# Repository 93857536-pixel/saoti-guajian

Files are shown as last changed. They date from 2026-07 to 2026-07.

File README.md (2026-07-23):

# 扫题挂件（Saoti GuaJian）

ESP32-S3 扫题挂件完整工程：固件、BLE Companion（iOS / watchOS / macOS）、USB 联调 App、装配与 3D 外壳。

## 仓库结构

| 目录 | 说明 |
|---|---|
| [`firmware/`](firmware/) | ESP32-S3 PlatformIO 固件（OV5640 / ST7789 / A7670G / BLE GATT / USB 串口） |
| [`companion/`](companion/) | **扫题挂件 App**（蓝牙）：iPhone + Apple Watch + Mac |
| [`macos-app/`](macos-app/) | macOS「SaotiCam」：USB 串口预览 / 联调 |
| [`hardware/`](hardware/) | 装配说明、接线、3D 外壳 STL/STEP |

架构：[`firmware/ARCHITECTURE.md`](firmware/ARCHITECTURE.md)  
BLE 协议：[`firmware/docs/BLE_COMPANION.md`](firmware/docs/BLE_COMPANION.md)

## 系统怎么用

1. 烧录 `firmware`（默认整机 env）
2. 屏上显示蓝牙名（如 `Saoti-F79D`）
3. 打开 **Companion App** →「设备」扫描连接（**不要**用 iPhone「设置 → 蓝牙」搜）
4. 短按 BOOT 或 App「扫题」→ 4G 调智谱 GLM-V → 答案经 BLE / 屏显示

AI 默认走 **4G only**（`NET_CELL_ONLY=1`）。USB 推流仍可用 Mac SaotiCam。

## Companion App（推荐日常使用）

```bash
cd companion
brew install xcodegen   # 若未安装
xcodegen generate
open SaotiCompanion.xcodeproj
```

| Scheme | 平台 |
|---|---|
| `SaotiCompanion` | iPhone（含 Watch App） |
| `SaotiCompanionMac` | Mac |

在 Xcode 填入 Team（Signing），真机调试蓝牙（模拟器无 BLE）。

功能：状态 / 远程扫题 / 答案全文 / 取景缩略图 / 补光；Watch 经 iPhone 转发命令。

## macOS USB 联调 App（SaotiCam）

```bash
cd macos-app
xcodegen generate
xcodebuild -scheme SaotiCam -configuration Debug -derivedDataPath build build
open build/Build/Products/Debug/SaotiCam.app
```

插入 CH343 / 原生 USB → 选端口 → 波特率 **115200**（4G）或 **921600**（USB 推流）→「连接」。

## 固件快速烧录

```bash
cd firmware
cp include/secrets.example.h include/secrets.h   # 首次，填入智谱 Key
pio run -e esp32s3-devkitc-1 -t upload          # 真屏 + 全功能（含 BLE）
# pio run -e esp32s3-devkitc-1-nolcd -t upload   # USB 推流联调（mock 屏）
# pio run -e esp32s3-devkitc-1-4gtest -t upload  # 4G 联调
```

常用串口命令：`?` 状态，`s` 扫题，`t` AI 测图，`DIAG` 4G，`V`/`v` USB 推流，`BLE` 自检广播。

关闭 BLE：编译加 `-DBLE_GATT_ENABLE=0`。

## 硬件要点

- 主控：YD-ESP32-S3 **N16R8**
- 摄像头：微雪 **OV5640 Camera Board (C)**（DVP；丝印 D2–D9→GPIO6–13）
- 屏幕：微雪 **1.3" ST7789**（`1/3/38/39/40/41`）
- 4G：FS-MCore **A7670**（ESP TX=21→模 RX，模 TX→ESP 2；PWK=47，PEN=48；VIN 独立 5V）
- 电池 ADC：GPIO14 分压
- 外壳 v7.36（76×110×58）：见 [`hardware/case/`](hardware/case/)，打印交付 `stl/saoti_front.stl` + `saoti_back.stl`

引脚以 [`firmware/include/pins.h`](firmware/include/pins.h) 为准。  
接线：[`hardware/WIRING.md`](hardware/WIRING.md)。

## License

个人/学习项目；按需自行补充许可证。

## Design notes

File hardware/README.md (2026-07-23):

# 硬件与外壳（v7.36）

| 文件 | 说明 |
|---|---|
| [`case/`](case/) | 卡扣外壳源码 + STL（**76×110×58 mm**） |
| [`case/PRINT.md`](case/PRINT.md) | 给商家打印说明 |
| [`case/COMPONENTS.md`](case/COMPONENTS.md) | 配件尺寸与舱位 |
| [`case/stl/saoti_front.stl`](case/stl/saoti_front.stl) / [`saoti_back.stl`](case/stl/saoti_back.stl) | **打印交付** |
| [`WIRING.md`](WIRING.md) / [`wiring_all.png`](wiring_all.png) | 全系统接线 |
| [`ASSEMBLY.md`](ASSEMBLY.md) | 装配长文（部分引脚可能过时，以 `firmware/include/pins.h` 为准） |
| [`给店家-接线说明.txt`](给店家-接线说明.txt) | 店家简版 |

生成外壳：

```bash
cd case
python3 generate_case.py
# 可选：配件就位预览
python3 generate_packed_assembly.py
```

材料：**PETG**；装配：卡扣，免胶免螺丝。

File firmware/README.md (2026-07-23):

# 扫题挂件固件

YD-ESP32-S3（N16R8）+ ST7789 + OV5640 + A7670。默认烧录即可用真屏整机固件。

3D 外壳（打印）：见 [`../hardware/case/PRINT.md`](../hardware/case/PRINT.md)，交付 `hardware/case/stl/saoti_front.stl` + `saoti_back.stl`。

**AI 解题**：默认 **只用 4G** 访问智谱 GLM-V（首选 `glm-4.6v`；用不了直接换 `glm-4v-flash`）。  
**4G**：开机拨号；SoftAP/家用 WiFi 已关闭（`NET_CELL_ONLY=1`）。预览可用 USB 串口推流。

## 功能清单

| 功能 | 状态 | 说明 |
|---|---|---|
| ST7789 显示 | 可用 | 状态页 + ASCII 答案摘要 |
| OV5640 拍照扫题 | 可用* | 短按 BOOT / 串口 `s` / SoftAP `/scan` |
| 无摄像头降级 | 可用 | 固定题图测 AI；长按 BOOT / `t` / SoftAP `/test` |
| SoftAP 控制台 | 默认关闭 | `NET_CELL_ONLY=1` 时不开热点 |
| 通义 VL 解题 | 4G + ESP-TLS | 模块只开 TCP，ESP32 mbedTLS 做 HTTPS |
| 4G A7670 | 默认 | 开机拨号；串口 `NET`/`DIAG`/`FW`/`HTEST` |
| USB 推流 | 可选 | 串口 `V`/`v` |

\* 成像质量取决于摄像头硬件与接线；微雪 C 型按 **D2–D9→GPIO6–13**（见 [WIRING.md](WIRING.md)）。

## 快速开始

```bash
cd firmware
cp include/secrets.example.h include/secrets.h   # 首次
# 编辑 secrets.h：OPENAI_API_KEY（智谱）+ 可上网 WiFi（CELL_ONLY 时可留空）
pio run -e esp32s3-devkitc-1 -t upload
```

1. 屏显示 Idle 提示（`BOOT to scan` 或 `BOOT=AI test`）
2. **短按 BOOT**：有摄像头则拍照解题；无摄像头则固定图测 AI  
3. **长按 BOOT ≈3s**：固定题图测 AI  
4. 手机连 SoftAP `SaotiCam` / `saoti1234` → `http://192.168.4.1/`  
5. 完整中文答案看 `/answer`

## 串口命令（115200）

| 命令 | 作用 |
|---|---|
| `s` | 扫题（同短按 BOOT） |
| `t` | 固定图 AI 测试 |
| `?` | JSON 状态 |
| `NET` / `DIAG` | 4G 诊断 |
| `V` / `v` | 开/关 USB 推流 |
| `APN=xxx` | 设置蜂窝 APN |
| `MODEL` | 查看当前视觉模型与已耗尽列表 |
| `MODEL=reset` | 清空「额度用尽」标记，从首选模型重试 |
| `SAY=文本` | TTS 播报（需接 UART 语音模块） |
| `TTS` / `TTSSTOP` | 查 TTS 状态 / 停止播报 |

## AI 配置

| 项 | 说明 |
|----|---|
| `include/secrets.h` | 智谱 Key + WiFi（已 gitignore） |
| 接口 | `open.bigmodel.cn/api/paas/v4/chat/completions` |
| 模型 | 默认 `glm-4.6v`；用不了直接换 `glm-4v-flash` |
| TTS | 可选 UART 模块 GPIO45/46；扫题成功自动播报 |

## 接线

详见 **[WIRING.md](WIRING.md)** 与 `include/pins.h`。

摘要：屏 SPI `1/3/38/39/40/41`；摄像 `4/5/6–13/15–18`；4G `ESP21→模RX`、`ESP2←模TX`、`PEN→48`、`PWK→47`；TTS `ESP45→模RX`、BUSY`46`；VIN 独立 5V。

## 环境

| env | 用途 |
|-----|---|
| `esp32s3-devkitc-1` | 整机（默认，启动探测 4G） |
| `esp32s3-devkitc-1-nolcd` | 无屏 USB 推流（跳过 modem） |
| `esp32s3-devkitc-1-4gtest` | 4G 联调 |
| `esp32s3-modem-bridge` | AT 透传 |
| `esp32s3-devkitc-1-mock` | 全 mock |

未配置 WiFi 时仍可 SoftAP 预览；解题需 STA 可上网。

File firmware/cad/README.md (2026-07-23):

# 3D 外壳（已迁走）

可打印外壳统一放在仓库根目录：

**[`../../hardware/case/`](../../hardware/case/)**

- 打印说明：[`PRINT.md`](../../hardware/case/PRINT.md)
- 配件尺寸：[`COMPONENTS.md`](../../hardware/case/COMPONENTS.md)
- 交付 STL：`saoti_front.stl` / `saoti_back.stl`（在 `stl/`）
- 生成：`python3 generate_case.py`

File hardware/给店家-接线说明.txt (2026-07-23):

================================================================================
  扫题挂件 — 给手机店 / 维修店师傅的完整接线说明
  （客户全部配件一次性安装，请严格按此操作，接完拍照发客户）
================================================================================

【客户配件清单 — 共 11 件，本说明全部覆盖】

  序号  配件名称                          本说明章节
  ────  ────────────────────────────────  ──────────
  1     YD-ESP32-S3 开发板                二、七
  2     OV5640 自动对焦摄像头             五
  3     ST7789 1.3寸 240×240 裸屏 12Pin   四
  4     FS-MC615-A7670CX 4G 模块 + 天线   三
  5     TP4056 Type-C 充放保护板          二-A
  6     603450 锂电池（带保护）           二-A
  7     MT3608 升压模块                   二-A、二-B
  8     2位独立按键模块（双键板）         六
  9     杜邦线 / 飞线                     全文
  10    Type-C 充电线（给 TP4056 充电）   二-A
  11    1000µF 16V 电解电容               二、三

  客户自备（本次可不装）：Nano SIM 物联卡、3D 打印外壳、万用表

【固件引脚已固定，必须按本说明接，否则 4G / 屏 / 摄像头无法工作】

================================================================================
★★★ 最重要：禁止把 4G 板直接叠插在 ESP32 排针上 ★★★
================================================================================

  · 必须用杜邦线/飞线逐根连接，不能整板对插！
  · 对插容易错一格，会出现 GND 接到 VIN，烧模块！
  · 4G 的 VIN 必须接 5V（右侧 5V 脚），不能靠叠插取电
  · 4G 的 TX/RX 必须交叉接到「模 RX←ESP 21」「模 TX→ESP 2」，不能接到左侧 TX/RX 字样（那是 USB）
  · 勿接旧表「TX→47 / PWK→41」（47 是 PWK，41 是屏幕背光）

================================================================================
一、安全（必看）
================================================================================

1. 电池红线 = 正，黑线 = 负，接反会烧板。
2. 先调 MT3608 空载到 5.0V，再接 ESP32 和 4G。
3. 4G 模块 VIN 必须 5V，禁止接 3.3V。
4. 1000µF 电容：长脚 + 接 5V，短脚 − 接 GND，不能接反。
5. 全部模块 GND 必须连在一起（共地）。
6. 4G 天线插紧；测试时不要用手握天线。
7. 接好线后若发烫、冒烟、有糊味，立即断电。

================================================================================
二、电源系统（TP4056 + 电池 + MT3608 + 电容）
================================================================================

── 二-A：TP4056 与电池 ──────────────────────────────────────

  TP4056 丝印        接什么
  ─────────────────────────────────────────────────────────
  B+  / BAT+         电池红线（+）
  B-  / BAT-         电池黑线（−）
  OUT+               红色导线 → MT3608 IN+
  OUT-               黑色导线 → MT3608 IN-（GND 母线）
  USB Type-C         Type-C 充电线（仅充电，不接 ESP32）

  ★ 建议：先不接电池，用 USB 给 TP4056 充电测试；最后一步再装电池。

── 二-B：MT3608 升压（必须调到 5.0V）────────────────────────

  MT3608 丝印        接什么
  ─────────────────────────────────────────────────────────
  IN+                TP4056 OUT+
  IN-                TP4056 OUT-
  OUT+               5V 红色母线（用万用表测量后再接负载）
  OUT-               GND 黑色母线

  调压步骤：
    1. 只接 TP4056 → MT3608，不接 ESP32 和 4G
    2. 给 TP4056 接 USB 或电池，输入约 3.7～4.2V
    3. 万用表测 MT3608 的 OUT+ 与 OUT- 之间电压
    4. 用小螺丝刀慢慢拧 MT3608 上的电位器，调到 5.0V（4.9～5.1 均可）
    5. 电压稳定后再往下接

── 二-C：5V 母线分配 ─────────────────────────────────────────

  MT3608 OUT+ (5V) ──┬── ESP32 右侧 5V
                     ├── 4G 模块 VIN
                     └── 1000µF 电容 +（靠近 4G 模块）

  MT3608 OUT- (GND) ─┬── ESP32 GND
                     ├── 4G 模块 GND
                     ├── TP4056 OUT-
                     ├── 屏幕 GND
                     ├── 摄像头 GND
                     └── 1000µF 电容 −

  屏幕、摄像头 3.3V ── ESP32 右侧 3V3（各一根，可并联）

  ★ ESP32 调试时可用 USB 线供电；装电池后整机由 MT3608 供电。
    不要 USB 和 MT3608 5V 同时硬并在一起（二选一或只接一种主供电）。

================================================================================
三、4G 模块 FS-MC615-A7670CX（对照模块边缘丝印）
================================================================================

  模块丝印     接到 ESP32 板子丝印         说明
  ─────────────────────────────────────────────────────────
  VIN          独立 5V≥2A（勿只靠 USB）    必须 5V，电流要够
  GND          GND                         共地
  RX           21（左侧排针「21」）        模块收 ← ESP 发（交叉！）
  TX           2（右侧排针「2」）          模块发 → ESP 收（交叉！）
  PWK          47（左侧排针「47」）        开机控制（固件脉冲）
  PEN          48 或 3V3                   使能，必须常高/常接 3.3V
  NET          悬空                        勿接 GPIO2（会顶 UART RX）
  天线座       FPC 天线                    插紧，金属面朝外

  ★ 左侧「TX」「RX」字样两针 = USB 口，不要接 4G！
  ★ 41=屏幕背光，勿再接 PWK；旧表「TX→47 / PWK→41 / NET→2」已作废。
  ★ 没插 SIM 卡也可以先接线测 AT（客户自己插卡）。

================================================================================
四、ST7789 1.3 寸裸屏 12Pin（3.3V，SPI）
================================================================================

  屏幕引脚名（常见）     接到 ESP32 丝印
  ─────────────────────────────────────────────────────────
  GND                    GND
  VCC / 3.3V             3V3
  SCL / SCLK             3
  SDA / MOSI / DIN       1
  CS                     38
  DC / RS                39
  RES / RST              40
  BL / 背光              41（或先接 3.3V 常亮试背光）

  ★ 以固件 pins.h 为准：MOSI=1 SCLK=3 CS=38 DC=39 RST=40 BL=41
  ★ 裸屏 12Pin 各卖家线序可能不同，必须对照客户提供的商家图纸！
  ★ 用万用表确认 VCC 脚后再上电，防止 VCC 接到信号脚烧屏。
  ★ 建议焊接或热缩管固定，杜邦线容易松。

================================================================================
五、OV5640 自动对焦摄像头（3.3V + 排线/多信号线）
================================================================================

  摄像头信号              接到 ESP32 丝印
  ─────────────────────────────────────────────────────────
  3.3V / VCC              3V3
  GND                     GND
  SDA / SIOD              4
  SCL / SIOC              5
  D0                      6
  D1                      7
  D2                      8
  D3                      9
  D4                      10
  D5                      11
  D6                      12
  D7                      13
  VSYNC                   16
  HREF                    17
  PCLK                    18
  XCLK                    15
  PWDN / RESET            可不接（悬空）

  排线安装：
    · 断电操作
    · 金属触点朝向 PCB
    · 插到底，扣紧卡扣
    · 撕掉镜头保护膜

  ★ 若摄像头是带转接板的小 PCB，请对照转接板丝印与上表连接。

================================================================================
六、拍照按键（2 位独立按键模块，双大方键板）
================================================================================

  客户配件：天猫「2位独立按键模块」（整板，不是单颗 6×6）。
  常见排针丝印：GND / KEY1 / KEY2（有的还有 VCC，接 3V3）。

  接线（装 3D 壳推荐）：
    KEY1 ──► ESP32 丝印「0」或 BOOT     （扫题）
    KEY2 ──► ESP32 丝印「42」           （测 AI）
    GND  ──► GND
    VCC  ──► 3V3（若模块有此脚）

  裸板联调也可先只按板载 BOOT（=GPIO0，等同 KEY1）。
  3D 外壳：后壳左侧壁双键方窗，模块从内侧嵌入。

================================================================================
七、USB 调试线（客户电脑烧录/测试用）
================================================================================

  · Type-C / Micro USB 线接 ESP32 上标「USB」或「COM」的口 → 电脑
  · 左侧 TX/RX 已被 USB 芯片占用，不要再接其他线

================================================================================
八、推荐安装顺序（师傅按步骤来）
================================================================================

  步骤 1   TP4056 + MT3608 接线，先不装电池
  步骤 2   万用表把 MT3608 调到 5.0V
  步骤 3   5V/GND 接 ESP32，上电看板载蓝灯亮、不发热
  步骤 4   接 ST7789 屏幕（3.3V + 35～40），看背光
  步骤 5   断电，插 OV5640 排线/信号线，再上电
  步骤 6   接 4G：VIN/GND/PEN/PWK/RX/TX/天线 + 1000µF 电容
  步骤 7   装 603450 电池到 TP4056（最后一步）
  步骤 8   全机共地检查、理线、固定（双面胶/热熔胶）
  步骤 9   拍照发客户（见下方清单）

================================================================================
九、接完必拍照片（发客户微信）
================================================================================

  [ ] 1. 整机俯视（所有模块可见）
  [ ] 2. 4G 模块接线特写（能看清 VIN/GND/RX/TX/PEN/PWK）
  [ ] 3. 电源接线特写（TP4056、MT3608、电容、电池）
  [ ] 4. 屏幕 / 摄像头接线特写
  [ ] 5. 万用表测 4G VIN 对 GND = 约 5.0V 的照片

================================================================================
十、接完自检清单（师傅打勾）
================================================================================

  电源
  [ ] MT3608 输出 5.0V（4.8～5.2V）
  [ ] 4G VIN 对 GND ≈ 5V（不是 0V，不是 3.3V）
  [ ] 4G PEN 对 GND ≈ 3.3V
  [ ] 1000µF 电容已装，正负未接反
  [ ] 所有 GND 相通

  4G
  [ ] 4G RX 接 ESP32「21」（不是左侧 TX/RX 字样）
  [ ] 4G TX 接 ESP32「2」（模块 TX → ESP 2，交叉）
  [ ] 4G PWK 接 ESP32「47」
  [ ] 4G PEN 接 ESP32「48」或 3V3
  [ ] 天线已插
  [ ] 没有用叠插方式连接（必须杜邦线/飞线）

  屏幕 / 摄像头
  [ ] 屏幕 VCC 接 3.3V（不是 5V）
  [ ] 屏幕 SPI：MOSI=1 SCLK=3 CS=38 DC=39 RST=40 BL=41
  [ ] 摄像头排线卡扣锁紧
  [ ] 摄像头 3.3V / GND 正确

  按键
  [ ] KEY1→GPIO0 扫题；KEY2→GPIO42 休眠/唤醒（或 BOOT 并联 KEY1）

  安全
  [ ] 无发烫、冒烟、糊味
  [ ] 电池正负未接反

================================================================================
十一、快速对照表（扫一眼）
================================================================================

  ESP32 丝印    接什么
  ─────────────────────────────────────
  5V            MT3608 OUT+、4G VIN、电容+
  3V3           4G PEN、屏幕 VCC、摄像头 VCC
  GND           全部 GND 汇在一起、电容−
  21            4G RX（模块的 RX 脚）← ESP 发
  2             4G TX（模块的 TX 脚）→ ESP 收
  47            4G PWK
  48            4G PEN（或直连 3V3）
  1             屏幕 MOSI/SDA
  3             屏幕 SCLK/SCL
  38            屏幕 CS
  39            屏幕 DC
  40            屏幕 RST
  41            屏幕 BL 背光
  4～18         摄像头（见第五节）
  0             KEY1 扫题 / BOOT
  42            KEY2 休眠/唤醒
  45            TTS TX（可选语音模块）
  46            TTS BUSY（可选）
  TX / RX       仅 USB，不接 4G

================================================================================
十二、常见错误（务必避免）
================================================================================

  ✗ 4G 板叠插在 ESP32 排针上           → 必烧或必乱
  ✗ GND 接到 4G VIN                    → 模块无电
  ✗ 4G TX/RX 接到左侧 TX/RX 字样       → 与 USB 冲突
  ✗ 4G VIN 接 3.3V                     → 模块不工作
  ✗ PEN 未接 3.3V                      → 模块不开机
  ✗ 屏幕 VCC 接 5V                     → 烧屏幕
  ✗ MT3608 超过 5.5V                   → 烧 ESP32/4G
  ✗ 电容正负接反                       → 危险

================================================================================
  接完后客户会用电脑烧录/测试；SIM 卡与 APN 由客户配置（固件 include/config.h 中 CELL_APN）。
  文档版本：2026-07-23  与生产固件 pins.h 一致（4G: TX/RX=21/2 PWK=47 PEN=48；屏: 1/3/38-41；摄: 4-18；键: 0/42）
================================================================================

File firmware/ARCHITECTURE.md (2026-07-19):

# 扫题挂件 — 项目总体架构

## 1. 系统目标

ESP32-S3「扫题挂件」：BOOT 键/串口触发 OV5640 拍照 → WiFi SoftAP 或 4G 上传 → ST7789 显示状态；Mac **SaotiCam** 可通过 USB 或 WiFi MJPEG 预览。

## 2. 最终接线（YD-ESP32-S3 N16R8）

| 模块 | 信号 | ESP 丝印 | 备注 |
|---|---|---|---|
| 微雪 ST7789 | VCC/GND | 3V3 / G | 勿用 5V 强行直灌裸屏 |
| | DIN/CLK/CS/DC/RST/BL | **1 / 3 / 38 / 39 / 40 / 41** | 勿用 35–37（OPI PSRAM） |
| OV5640 | SCCB/DVP | 4–5, 6–13, 15–18 | 既有映射 |
| FS-MCore 4G | TX/RX/PEN/PWK | 模TX→**2**，模RX→**21**，PEN→**48**，PWK→**47** | VIN 独立 5V≥2A；NET 悬空 |
| 拍照键 | 板载 BOOT | **0** | 短按拍照；3D 壳开孔露出，不另接按键 |

```
电源: 电池 → TP4056 → MT3608(5.0V) → ESP 5V + 4G VIN（共地，近 4G 加 1000µF）
```

## 3. 固件模块

```
main.cpp
  ├─ Display     ST7789（TFT_eSPI + HSPI）
  ├─ Camera      OV5640 JPEG
  ├─ Modem       A7670 AT + SoftAP WiFi 双路径
  ├─ Button      GPIO0
  ├─ UsbStream   SC 协议推流
  ├─ StreamServer SoftAP MJPEG :80
  └─ ble_gatt    BLE Companion GATT（Saoti-XXXX）
```

流程：`Idle → 按键/s → Capture → Upload → Result → Idle`

## 4. 编译环境

| env | 用途 |
|-----|---|
| `esp32s3-devkitc-1` | **默认整机**：真屏+摄+4G 快探+USB/WiFi 推流 |
| `esp32s3-devkitc-1-nolcd` | 无屏 USB 推流联调 |
| `esp32s3-devkitc-1-4gtest` | 专注 4G AT |
| `esp32s3-modem-bridge` | 电脑直发 AT 透传 |
| `esp32s3-devkitc-1-mock` | 全 mock |

```bash
cd firmware
pio run -e esp32s3-devkitc-1 -t upload
```

## 5. 使用

1. 上电后屏显示 Boot → Ready / net offline  
2. 手机连 SoftAP `SaotiCam` / `saoti1234`，打开 `http://192.168.4.1/`  
3. 按 **BOOT** 或串口发 `s` 拍照上传  
4. Mac：原生 USB 或 CH343；`V` 开 USB 推流，`m` 做 4G 深诊断  

## 6. 已知限制

| 项 | 说明 |
|----|---|
| 4G 仅红灯 | 模块未开机，需独立 5V≥2A；程序已快失败，不阻塞整机 |
| GPIO35–37 | N16R8 OPI 占用，不能接屏 |
| GPIO47 | PSRAM 时钟干扰，不能接 4G RX |

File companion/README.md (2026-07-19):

# 扫题挂件 Companion（iOS / watchOS / macOS）

通过 **蓝牙** 连接 ESP32 扫题挂件：状态、远程扫题、答案全文、取景缩略图、补光。

固件协议见 [`../firmware/docs/BLE_COMPANION.md`](../firmware/docs/BLE_COMPANION.md)。

## 打开工程

```bash
cd companion
xcodegen generate
open SaotiCompanion.xcodeproj
```

| Scheme | 平台 |
|---|---|
| `SaotiCompanion` | iPhone（含 Watch App） |
| `SaotiCompanionMac` | Mac |

在 Xcode 里填入你的 **Team**（Signing），真机调试蓝牙（模拟器无 BLE）。

## 功能

- **控制**：电量 / 4G / 相位；一键扫题、唤醒、补光  
- **取景**：按需拉一帧缩略图（非实时流）  
- **答案**：当前全文 + 本地历史  
- **设备**：扫描 `Saoti-*`、连接、日志  
- **Watch**：扫题 / 唤醒 / 进度与答案摘要（依赖 iPhone 已连挂件）

## 重要

iPhone「设置 → 蓝牙」**不会**列出本挂件（自定义 GATT）。请在本 App「设备」页扫描；对照挂件屏幕上的 `Saoti-XXXX`。

## 权限

- `NSBluetoothAlwaysUsageDescription`  
- Background：`bluetooth-central`（扫题过程中保持连接）

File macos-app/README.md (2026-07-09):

# SaotiCam macOS 客户端

在 Mac 上通过 WiFi 实时查看 ESP32-S3 + OV5640 摄像头的 MJPEG 视频流。

## 前置条件

1. 已将 [saoti-guajian-fw](../saoti-guajian-fw/) 固件烧录到 ESP32-S3 开发板
2. 摄像头模块接线正确，串口可看到 `[STREAM] MJPEG http://...` 日志
3. macOS 已安装 Xcode 与 xcodegen（`brew install xcodegen`）

## 快速开始

### 1. 烧录固件

```bash
cd ../saoti-guajian-fw
python3 -m platformio run -e esp32s3-devkitc-1-nolcd -t upload
```

若 `config.h` 中 `WIFI_SSID` 仍为 `"YOUR_SSID"`，设备会自动开启 SoftAP，无需家庭 WiFi。

### 2. 连接网络

**方式 A — Mac 直连热点（默认）**

| 项目 | 值 |
|---|-----|
| WiFi 名称 | `SaotiCam` |
| 密码 | `saoti1234` |
| 设备 IP | `192.168.4.1` |

在 Mac 系统设置 → WiFi 中连接 `SaotiCam` 热点。

**方式 B — 同一局域网**

在固件 `config.h` 填写家庭 WiFi 的 `WIFI_SSID` / `WIFI_PASS`，烧录后查看串口日志中的 STA IP（如 `192.168.1.xxx`），Mac 连同一 WiFi 后在 App 输入该 IP。

### 3. 编译运行 macOS App

```bash
cd /Users/linminhao/Documents/saoti-guajian-ios
xcodegen generate
open SaotiCam.xcodeproj
```

在 Xcode 中选择 **My Mac** 运行，或命令行构建：

```bash
xcodebuild -scheme SaotiCam -destination 'platform=macOS' build
```

构建完成后可在 `DerivedData` 或 Xcode 中直接 Run 启动 App。

### 4. 使用 App

**USB 串口（推荐，无需 WiFi）**

1. ESP32 用 USB 线连 Mac（烧录口即可）
2. 打开 SaotiCam，连接方式选 **USB 串口**
3. 串口选 `cu.usbserial-...`，点击 **连接**

**WiFi**

1. Mac 连接 `SaotiCam` 热点或同一局域网
2. 连接方式选 **WiFi**，IP 填 `192.168.4.1`（或 STA IP）
3. 点击 **连接**

点击画面可隐藏/显示控制栏；点击 **断开** 停止拉流。

> USB 模式固件默认跳过 4G 初始化，启动更快、串口不被 AT 日志干扰。

## HTTP 端点（固件提供）

| 路径 | 说明 |
|---|---|
| `GET /stream` | MJPEG 实时流（multipart/x-mixed-replace） |
| `GET /capture` | 单张 JPEG 快照 |
| `GET /` | 状态页（含流预览链接） |

## 故障排查

- **连接失败**：确认 Mac 已连上 `SaotiCam` 热点或同一局域网；浏览器访问 `http://192.168.4.1/` 验证
- **无画面**：查看串口是否有 `[CAM]` / `[STREAM]` 日志；确认 OV5640 初始化成功
- **ATS 报错**：App 已配置本地 HTTP 例外；若 IP 不在 192.168.x.x 段，需在 `Info.plist` 补充对应域

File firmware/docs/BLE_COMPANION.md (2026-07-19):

# 扫题挂件 BLE Companion 协议

ESP32-S3 **硬件自带 BLE**；固件启用 GATT 后，广播名形如 `Saoti-XXXX`（MAC 后四位）。

Apple 工程：[`../../companion`](../../companion)（iOS / macOS / watchOS）。

## 服务 UUID

| 角色 | UUID |
|---|---|
| Service | `6E400001-B5A3-F393-E0A9-E50E24DCCA9E` |
| STATUS（Read+Notify） | `6E400002-…` |
| COMMAND（Write） | `6E400003-…` |
| ANSWER（Read+Notify） | `6E400004-…` |
| THUMB（Notify） | `6E400005-…` |
| EVENT（Notify） | `6E400006-…` |

协议版本：`fw_proto=1`（见 STATUS JSON）。

## COMMAND 文本

| 命令 | 作用 |
|---|---|
| `ping` | EVENT 回 `pong` |
| `scan` / `s` | 触发扫题（等同 BOOT） |
| `wake` | 唤醒摄像头/4G |
| `thumb` / `preview` | 抓一帧 QVGA 预览图经 THUMB 下发（非扫题原图） |
| `flash=1` / `flash=0` | 补光开关 |
| `status` | 立即推送 STATUS |
| `answer` | 推送当前答案 |

## STATUS JSON（节选）

`cam` `lcd` `cell` `bat_pct` `charging` `csq` `sleeping` `busy` `phase` `fw` `fw_proto` `ble` `has_answer` `last_error` …

`phase`：`idle` | `capturing` | `uploading` | `result`

## THUMB 分片

1. 首包 8 字节：`THMB` + `uint32` little-endian 长度  
2. 后续 Notify：JPEG 原始字节（约 180B/包）

## 烧录与验证

```bash
cd firmware
pio run -e esp32s3-devkitc-1 -t upload
# 串口应出现：[BLE] advertising as Saoti-XXXX
```

手机/Mac 打开 **扫题挂件** App → 设备页扫描 → 连接 → 控制页扫题。

## 重要：为什么「手机设置 → 蓝牙」搜不到？

| 平台 | 系统蓝牙设置 |
|---|---|
| **iPhone / iPad** | **永远不会**列出本挂件（自定义 GATT，非耳机/键盘类） |
| **Android** | 部分机型在「配对新设备」里能看到 `Saoti-XXXX`，但仍需 App 才能扫题 |
| **正确做法** | 打开 **扫题挂件 Companion App** →「设备」→ 扫描 → 点 `Saoti-XXXX` |

挂件屏幕空闲时会显示蓝牙名（如 `Saoti-F79D`）和「请用扫题挂件App连接」。

## 说明

- V1 **不做** BLE 实时视频；实时预览仍用 SoftAP/USB（Mac SaotiCam）。  
- Watch 经 iPhone WatchConnectivity 转发，不直接连挂件。  
- 关闭 BLE：编译加 `-DBLE_GATT_ENABLE=0`。

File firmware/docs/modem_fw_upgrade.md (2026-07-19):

# FS-MCore A7670G 基带固件升级（解决 HTTPS 715）

本机实测（2026-07-18 `FW`）：

| 项 | 值 |
|----|-----|
| Model | **A7670G-LABE** |
| Revision | **A110B06A7670M7**（`A7670M7_B06V01_241111`） |
| ATI 显示 | V1.11.2 |
| IMEI | `867284069506675` |
| 现象 | `httpbin.org` HTTPS OK；百炼 → **715 SSL 失败** |

**结论：本机已是公开渠道最新的 LABE 包（A110B06），再刷同一包通常无效。**  
若店家另有更新私有包可再试；否则应改走 **ESP 侧 TLS（方案 1）**，不要刷 LASE/LLSE。

---

## 警告（必读）

1. **只能刷 A7670G-LABE 包**。刷成 LASE / LLSE / A7670E 等会导致变砖或反复重启。
2. 升级工具是 **Windows** 程序；Mac 不能直接烧录基带。
3. 用 **V1.32** 烧录工具，**不要**用有 bug 的 V1.13。
4. 升级前记下 `FW` 输出的完整 `AT+SIMCOMATI` 和 IMEI；个别包会清 IMEI，可用 `AT+SIMEI="你的号码"` 写回。
5. **优先问店家**要「A7670G-LABE」官方升级包；第三方包仅作备选。

---

## 需要准备

- Windows 电脑
- 模块 **Type-C USB** 线
- 模块 **VIN 独立 5V ≥2A**（升级时也建议外供），GND 与电脑共地
- PEN 接 3.3V（或 ESP 的 3V3）
- 驱动 + 烧录工具（LilyGo 汇总，与 SIMCom MADL 同源）：
  - 驱动：[Windows USB Drivers](https://drive.google.com/drive/folders/1-7x2z00a5VO7GZS96C6mDupNTBXIh--H)
  - 工具（选 **V1.32**）：[A7670X/A7608X Flash Tools](https://drive.google.com/file/d/12nt5-wcsUT6bRaEhfOMBSq0EhOl8R2by/view?usp=sharing)
- 固件包（**仅 LABE**，备选）：
  - 🆕 [A7670G-LABE A110B06](https://drive.google.com/file/d/10fsorFI8SuTlcffufgphpYbt2JjUpqtg/view?usp=sharing)
  - 回退用 [A7670G-LABE A069B01](https://drive.google.com/file/d/10oSTTqhw7ZiiZ_LiqAb3WYV3LXwbpKtV/view?usp=sharing)

图文总览（LilyGo）：  
https://github.com/Xinyuan-LilyGO/LilyGo-Modem-Series/blob/main/docs/cn/update_fw.md  
视频参考：https://youtu.be/AZkm-Z7mKn8

---

## 步骤

### 1. 升级前备份版本

ESP 已接好时，串口（115200）发：

```text
FW
```

应看到 `Model: A7670G-LABE`。把整段 `SIMCOMATI` 复制保存。

或用店家 **FreeAT**：模块 USB 插 Windows → `AT+SIMCOMATI`。

### 2. 进入升级模式（BOOT）

FS-MCore 上找 **BOOT / SBOOT / BOOT_N** 焊盘或按键（店家资料图为准）：

1. **按住 BOOT 不放**
2. 插上模块 Type-C（必要时再接 VIN 5V）
3. Windows「设备管理器」出现下载口 / 未知设备后，再松开 BOOT
4. 按工具说明给所有未知设备装驱动（可能有多个，逐个装完）

若没有按键：用杜邦线在上电瞬间把 BOOT 脚拉到说明书要求的电平（通常对地或对 1.8V，以店家为准）。

### 3. 用 MADL V1.32 烧录

1. 解压固件包，打开 **`A76XX_A79XX_MADL V1.32 Only for Update`**
2. 选择解压出的 **A7670G-LABE** 镜像目录
3. 选中设备管理器里的下载 COM 口
4. 点 **GO**，等进度条跑完，不要中途拔线

### 4. 升级后核对

正常上电（不必再按 BOOT），串口发：

```text
FW
```

期望类似：

```text
Model: A7670G-LABE
Revision: A110B06A7670M7
...
```

然后：

```text
HTEST
t
```

- `HTEST` → httpbin 仍应 200  
- `t` → 若百炼不再 715，说明 TLS 已改善  

若 IMEI 变空：在 FreeAT / 透传里执行 `AT+SIMEI="原IMEI"`（以 SIMCom 手册为准）。

---

## 失败时

| 情况 | 处理 |
|---|---|
| 刷错成 LLSE/LASE | 立刻用 **LABE** 包再刷回去 |
| A110B06 后不稳定 | 回退 **A069B01**，再考虑方案 1（ESP 侧 TLS） |
| 仍 715 | 升级未必能覆盖百炼的密码套件；改走 ESP mbedTLS over 4G TCP |

升级完成后把串口 `FW` + `HTEST` / `t` 日志发我，我帮你看是否打通百炼。

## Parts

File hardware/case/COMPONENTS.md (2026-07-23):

# 配件尺寸 + 舱位安装（外壳 v7.36）

> 外廓 **76×110×58**。挂绳耳对接；卡扣台肩；止口连体；四角/勾尖留壁 ≥0.5 mm。

## 1. 配件尺寸

| 配件 | 平面 (mm) | 备注 |
|---|---|---|
| YD-ESP32-S3 | 64 × 28.4 | 烧录口 **12×5** |
| 微雪 1.3" LCD | 45 × 31 | **仅前壳** |
| OV5640 (C) | **35.70 × 23.90** | 外窗 **25×10** |
| 电源总成 | 63 × 40 × 24 | 背开关对准 |
| A7670 4G | ≈28 × 26 | 后壳上右 |

## 2. 舱位

底电源 → 中 ESP → 上左摄像 / 上右 4G；屏在前壳。

## 3. 外壳

| 项 | mm |
|----|-----|
| 外廓 | 76 × 110 × 58 |
| 前/后深 | 26 / 32 |
| 摄像外窗 | 25 × 10 |
| 挂绳耳 | 前后对接，孔 Ø6 |
| 卡扣 | 8 枚，横梁台肩 |

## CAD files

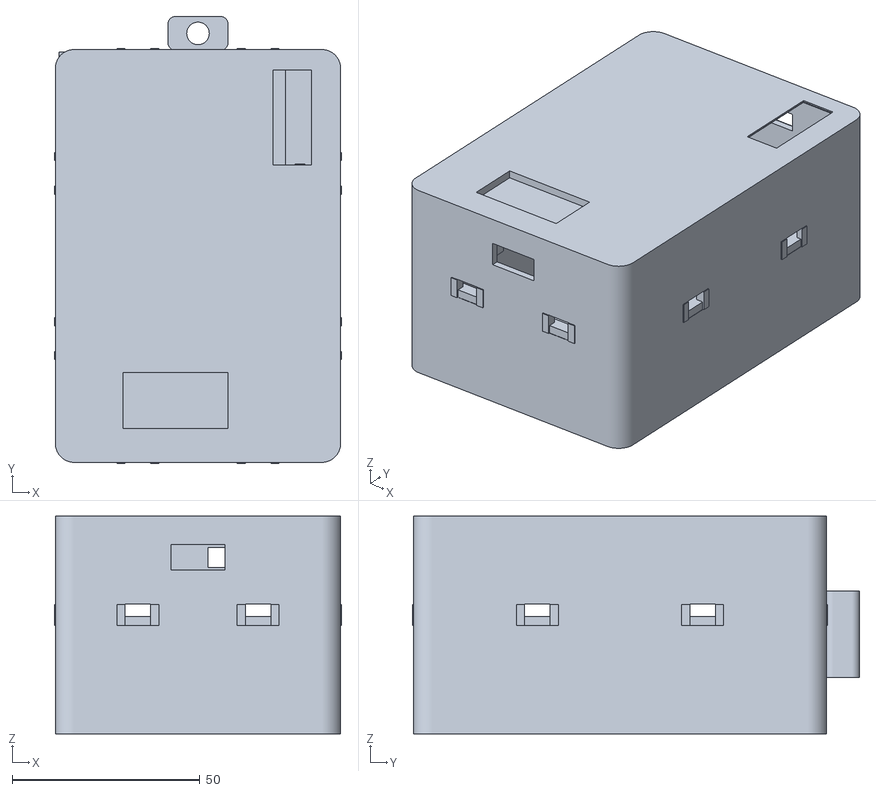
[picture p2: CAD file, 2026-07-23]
hardware/case/stl/saoti_assembled_preview.stl
76.6 x 119.1 x 58.0

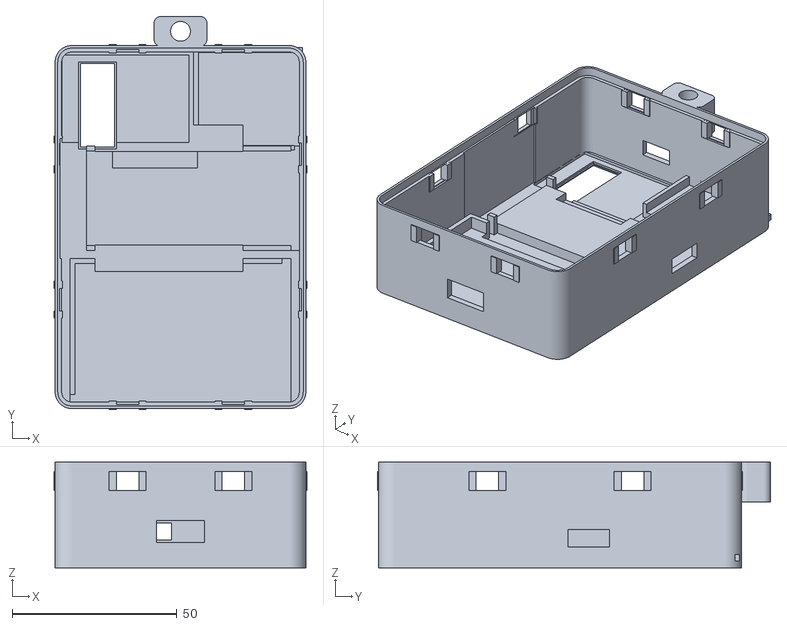
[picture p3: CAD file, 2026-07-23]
hardware/case/stl/saoti_back.stl
76.6 x 119.1 x 32.0

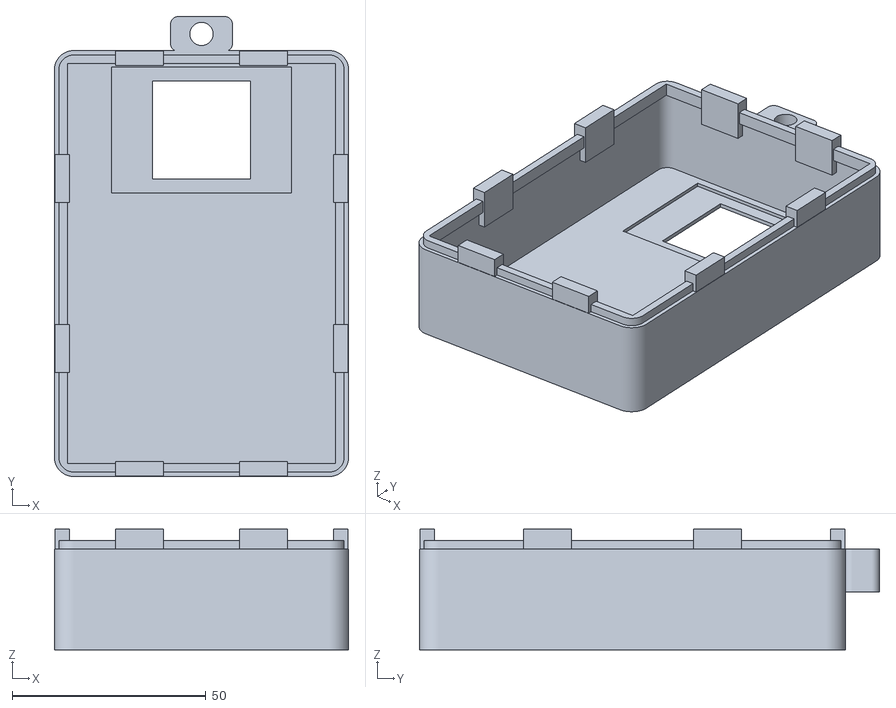
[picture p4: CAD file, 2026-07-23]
hardware/case/stl/saoti_front.stl
76.0 x 118.8 x 31.2

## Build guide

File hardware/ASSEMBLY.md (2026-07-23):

# 扫题挂件 — 硬件安装与组装指南

> **⚠️ 本文已过时（v1.0 / 100×100×100 立方壳），勿按本文引脚与外壳尺寸施工。**  
> **现行标准请以以下文件为准：**
> - 引脚：[`firmware/include/pins.h`](../firmware/include/pins.h)
> - 接线：[`WIRING.md`](WIRING.md) / [`给店家-接线说明.txt`](给店家-接线说明.txt)
> - 外壳 v7.36（**76×110×58 mm**）：[`case/PRINT.md`](case/PRINT.md) / [`case/COMPONENTS.md`](case/COMPONENTS.md)
> - 生成脚本：`case/generate_case.py`（不是旧的 `generate_enclosure.py`）
>
> 下文仅作电源/安全/组装流程参考；引脚表与外壳章节如有冲突，**一律以上述现行文件为准**。

> **版本**：v1.0（归档）  
> **适用方案（已废弃）**：方案 A（100×100×100 mm 立方体外壳）  
> **现行主控**：YD-ESP32-S3 N16R8  
> **目标读者**：首次接触 ESP32、锂电池与 4G 模块的初学者  

---

## 目录

1. [文档概述与 BOM 清单](#1-文档概述与-bom-清单)
2. [所需工具与耗材](#2-所需工具与耗材)
3. [安全须知](#3-安全须知)
4. [开箱验货 Checklist](#4-开箱验货-checklist)
5. [电源子系统组装](#5-电源子系统组装)
6. [推荐引脚接线表](#6-推荐引脚接线表)
7. [分阶段组装步骤](#7-分阶段组装步骤)
8. [MT3608 调压步骤](#8-mt3608-调压步骤)
9. [A7670G SIM 卡安装与 AT 联网测试](#9-a7670g-sim-卡安装与-at-联网测试)
10. [各模块独立测试步骤](#10-各模块独立测试步骤)
11. [3D 外壳安装要点](#11-3d-外壳安装要点)
12. [整机上电与验收 Checklist](#12-整机上电与验收-checklist)
13. [常见问题排查表](#13-常见问题排查表)
14. [建议组装顺序时间线](#14-建议组装顺序时间线)

---

## 1. 文档概述与 BOM 清单

### 1.1 项目概述

扫题挂件是一款约 **10×10×10 cm** 的便携立方体设备，具备：

| 功能 | 硬件 |
|---|---|
| 图像采集 | OV5640 自动对焦摄像头 |
| 本地显示 | ST7789 1.3 寸 240×240 IPS 屏 |
| 蜂窝联网 | A7670G 4G Cat-1 模块（全球版 AT） |
| 主控计算 | ESP32-S3-DevKitC-1（16 MB Flash + 8 MB PSRAM） |
| 供电 | 603450 1200 mAh 锂电 + TP4056 充放保护 + MT3608 升压 |

**推荐组装策略**：先**裸板分模块联调**，确认屏幕、摄像头、4G、按键均正常后，再**叠加固定**并**装入 3D 外壳**。

### 1.2 3D 外壳文件（本目录）

| 文件 | 说明 |
|---|---|
| `saoti_guajian_body.stl` / `.step` | 下壳（主体），高度 **92 mm** |
| `saoti_guajian_lid.stl` / `.step` | 上盖，高度 **8 mm**，含挂绳孔 |
| `generate_enclosure.py` | CadQuery 外壳生成脚本（可重新导出 STL/STEP） |
| `打印说明-给商家.txt` | 发给 3D 打印商家的工艺说明 |

**外轮廓尺寸**：100 × 100 × 100 mm（下壳 92 mm + 上盖 8 mm）  
**内腔尺寸**：约 96 × 96 × 90 mm，壁厚 2 mm  
**坐标系**：原点在立方体**左后下角** — X 向右，Y 向里（深度），Z 向上

### 1.3 已购 BOM 对照表

| 序号 | 模块 | 规格/型号 | 店铺 | 数量 | 备注 |
|---|---|---|---|---|---|
| 1 | 主控开发板 | ESP32-S3-DevKitC-1 **N16R8** | 泽杰旗舰店 | 1 | 16 MB Flash + 8 MB OPI PSRAM |
| 2 | 摄像头 | OV5640 **自动对焦**（采购套餐） | 贝科姆 | 1 | 确认排线、镜头保护膜 |
| 3 | 显示屏 | ST7789 **1.3 寸 240×240 IPS**，插接式 **12 Pin 裸屏** | 深超（中景园） | 1 | 无 PCB 转接板，需飞线或自制转接 |
| 4 | 4G 模块 | **A7670G 全球版-AT MCore** + FPC 天线 | 飞思创 | 1 | AT 固件，Nano SIM |
| 5 | 充电模块 | TP4056 **3.7 V 带过充放保护 Type-C** | 天麟 | 1 | 带保护板，非裸 TP4056 |
| 6 | 锂电池 | **603450 1200 mAh** 带保护板 | 科创新能源 | 1 | 尺寸约 6×34×50 mm |
| 7 | 升压模块 | **MT3608** 可调升压 | 电子爱好者之家 | 1 | 输出需调至 5.0 V |
| 8 | 按键 | **2 位独立按键模块**（双键 PCB） | 天猫电子积木款 | 1 | KEY1→GPIO0，KEY2→GPIO42；见 WIRING.md |
| 9 | 杜邦线 | 母对母 **40 P 20 cm** | 跃动芯火 | 1 排 | 建议再备公对母 |
| 10 | 数据线 | Type-C 数据线 **30 cm** | 跃动芯火 | 1 | 充电与串口调试 |
| 11 | 电解电容 | **16 V 1000 µF 8×12** | 深圳顺兴达 | 1 | 抑制 4G 脉冲电流 |

### 1.4 用户自行准备

| 物品 | 用途 |
|---|---|
| Nano SIM / 物联网卡 | A7670G 蜂窝联网（需已激活、有流量） |
| 数字万用表 | MT3608 调压、排查短路 |
| 3D 打印外壳 | 本目录 STL/STEP，PETG/ABS 推荐 |
| （强烈建议）热缩管、电工胶带 | 绝缘与固定 |
| （建议）M3×6 螺丝 + 螺母 | 四角加强固定（见打印说明） |
| （建议）泡棉双面胶 / 3M VHB | 固定电池与天线 |
| （可选）ESP32 USB 串口驱动 | macOS 通常免驱；Windows 需 CP210x/CH340 驱动 |

---

## 2. 所需工具与耗材

### 2.1 必备工具

| 工具 | 用途 |
|---|---|
| 数字万用表 | 测电压、通断、确认极性 |
| 十字/一字小螺丝刀 | 轻触开关、模块端子 |
| 尖嘴钳 | 剥线、折引脚 |
| 侧剪钳 | 剪杜邦线、引脚 |
| USB Type-C 线 | 充电、ESP32 烧录与串口监视 |
| 电脑（Windows/macOS/Linux） | 烧录固件、串口 AT 测试 |

### 2.2 建议工具

| 工具 | 用途 |
|---|---|
| 电烙铁 + 焊锡（含松香） | ST7789 裸屏 12 Pin 飞线更可靠 |
| 热缩管 / 电工胶带 | 防止短路 |
| 扎带 / 双面胶 | 线束整理 |
| 镊子 | 插 SIM 卡、夹小件 |
| 标签纸 / 记号笔 | 标注线序（强烈建议） |
| 手机（手电筒） | 检查壳内是否顶线 |

### 2.3 耗材

| 耗材 | 用量建议 |
|---|---|
| 杜邦线母对母 | 30～50 根 |
| 1000 µF 电解电容 | 1 个（4G 供电滤波） |
| 热缩管 | 若干 |
| 泡棉垫 | 电池与外壳缓冲 |

---

## 3. 安全须知

> **锂电池操作不当可能导致起火、膨胀或爆炸。请逐条阅读。**

### 3.1 锂电池

1. **极性不可接反**：电池红线/标记 **+** 接 **BAT+ / OUT+**；黑线 **−** 接 **BAT− / OUT−**。接反可能瞬间损坏 TP4056、升压模块及开发板。
2. **禁止短路**：电池正负极、焊点、杜邦线金属部分不可互相触碰。
3. **禁止刺穿、弯折、加热**电池；膨胀/漏液/发热的电池**立即停用**并安全处置。
4. 首次焊接或接线后，用万用表 **直流电压档** 确认电池端约 **3.7～4.2 V**，且无异常发热。
5. 充电请在**通风**环境进行；人不在场时**不要**长时间无人值守充电（尤其首次）。

### 3.2 极性与接地

1. 全机采用**共地**：TP4056、MT3608、ESP32、A7670G、屏幕、摄像头 **GND 必须相连**。
2. 电解电容：**长脚 +** 接 **5 V 正**，**短脚 −** 接 **GND**；焊反可能爆炸。
3. ESP32-S3 的 **3.3 V 逻辑** 不可直接接 **5 V** 到 GPIO（部分模块 TX/RX 需确认电平）。

### 3.3 首次上电流程

```
① 万用表确认 MT3608 空载输出 ≈ 5.0 V
② 断开 A7670G 与摄像头等大电流负载，仅给 ESP32 上电
③ 测量 ESP32 板上 3.3 V 引脚电压正常（约 3.2～3.4 V）
④ 再逐一接入 ST7789 → OV5640 → A7670G
⑤ 每接入一个模块，观察是否发热、重启、屏幕花屏
```

### 3.4 4G 模块特别注意

- A7670G 发射瞬间电流可达 **1～2 A 峰值**，务必：
  - 使用**粗短**电源线（电池 → MT3608 → 负载）
  - 在 **5 V 母线** 近 A7670G 处并联 **1000 µF 电容**
  - 避免仅用 ESP32 板载 3.3 V 给 4G 模块供电

### 3.5 静电与操作

- 触摸金属接地物释放静电后再摸芯片引脚。
- 插拔摄像头排线时**断电**；捏住插头两侧，不要拽排线。

---

## 4. 开箱验货 Checklist

逐项打勾，异常先联系卖家，**不要**带着故障件继续组装。

### 4.1 ESP32-S3-DevKitC-1

- [ ] 板面无裂纹、无元件缺失
- [ ] USB Type-C 口无松动
- [ ] 上电后电源 LED 亮（USB 供电测试）
- [ ] 电脑识别串口（macOS：`/dev/cu.usbmodem*` 或类似）
- [ ] 确认丝印型号含 **N16R8**（16 MB Flash + 8 MB PSRAM）

### 4.2 OV5640 摄像头模块

- [ ] 模组 PCB 完整，镜头有保护盖/膜
- [ ] 排线无折痕、插座卡扣正常
- [ ] 排线方向说明书与插座缺口一致
- [ ] （可选）用万用表测 3.3 V / GND 无短路

### 4.3 ST7789 1.3 寸裸屏

- [ ] 玻璃无裂纹、无大面积划痕
- [ ] 12 Pin 排针无弯折
- [ ] 背面驱动 IC 无虚焊
- [ ] 确认是 **240×240 IPS**（非 240×320 等其他分辨率）

### 4.4 A7670G MCore

- [ ] 模块本体无磕碰
- [ ] **FPC 天线**未撕裂（先不要过度弯折）
- [ ] Nano SIM 卡槽弹簧正常
- [ ] 天线接口已拧紧/插牢（如有 SMA/IPEX 转接）
- [ ] 确认套餐为全球版 **A7670G-AT**

### 4.5 TP4056 充放保护模块

- [ ] Type-C 口正常
- [ ] 标注 **B+ / B− / OUT+ / OUT−** 清晰
- [ ] 充电指示 LED 插入 USB 会亮/变化
- [ ] 保护芯片无烧痕

### 4.6 603450 锂电池

- [ ] 电压约 **3.7～3.9 V**（出厂存储电压）
- [ ] 保护板包覆完整
- [ ] 无鼓包、无异味
- [ ] 尺寸能放入壳体（约 6×34×50 mm）

### 4.7 MT3608 升压模块

- [ ] 可调电位器可旋转
- [ ] IN+/IN−、OUT+/OUT− 标识清晰
- [ ] 先用 USB 或可调电源 **单独测试**（见第 8 章）

### 4.8 轻触开关

- [ ] 按下手感清脆，松手回弹
- [ ] 四脚通断符合预期（对角相通）

### 4.9 1000 µF 电容

- [ ] 引脚无腐蚀
- [ ] 标注 **16 V 1000 µF**
- [ ] 确认 **长脚为正**

---

## 5. 电源子系统组装

### 5.1 系统电源架构

本机采用 **单节 3.7 V 锂电 → 升压 5 V → 各模块** 的架构：

```
                    ┌─────────────────────────────────────────┐
                    │              负载分配                    │
                    │  ESP32-S3 (5V→板载3.3V)                 │
                    │  A7670G MCore (5V 或 VBAT)              │
                    │  OV5640 / ST7789 (3.3V 由 ESP32 引出)   │
                    └─────────────────────────────────────────┘
                                        ▲
                                        │ 5.0 V（调整后）
                    ┌───────────────────┴───────────────────┐
                    │            MT3608 升压模块              │
                    │  IN+ / IN−  ← 电池经 TP4056 保护输出    │
                    │  OUT+ / OUT− → 5V 母线 + 1000µF 到 GND   │
                    └───────────────────┬───────────────────┘
                                        │
                    ┌───────────────────┴───────────────────┐
                    │     TP4056（Type-C 充放保护一体）       │
                    │  B+ / B−  ←→  603450 电池              │
                    │  OUT+ / OUT− → 整机电池正/负母线        │
                    │  USB-C ← 外部充电                        │
                    └───────────────────────────────────────┘
```

### 5.2 接线表（电源部分）

| 从 | 到 | 线色建议 | 说明 |
|----|----|---|---|
| 电池 **+** | TP4056 **B+** | 红 | 先不要插电池，最后确认再接入 |
| 电池 **−** | TP4056 **B−** | 黑 | 共地基准 |
| TP4056 **OUT+** | MT3608 **IN+** | 红 | 受保护电池正 |
| TP4056 **OUT−** | MT3608 **IN−** | 黑 | 电池负/系统地 |
| MT3608 **OUT+** | 5 V 母线（红） | 红 | **调压至 5.0 V 后再接负载** |
| MT3608 **OUT−** | GND 母线（黑） | 黑 | 全机共地 |
| 5 V 母线 | ESP32 **5V** 或 **VIN** | 红 | DevKitC-1 可从 5V 引脚供电 |
| 5 V 母线 | A7670G **VCC/5V** | 红 | 以模块丝印为准 |
| GND 母线 | ESP32 **GND** | 黑 | 至少 2 根降低阻抗 |
| GND 母线 | A7670G **GND** | 黑 | 粗短为佳 |
| 1000 µF **+** | 5 V 母线 | — | 靠近 A7670G |
| 1000 µF **−** | GND 母线 | — | 注意极性 |

> **TP4056 OUT 与 BAT 关系**：带保护板模块的 **OUT+/OUT−** 为对外供电端；充电时仍可从 OUT 取电，但大电流 4G 发射时电压会跌落，务必加 **1000 µF** 并缩短路径。

### 5.3 ASCII 接线图

```
  [USB Type-C 充电器]
         │
         ▼
  ┌──────────────┐
  │   TP4056     │
  │  B+    B−    │◄─── [603450 电池 + −]
  │  OUT+ OUT−   │───┐
  └──────────────┘   │
                     │ 3.7～4.2 V
                     ▼
              ┌─────────────┐
              │   MT3608    │
              │ IN+    IN−  │
              │ OUT+  OUT−  │─── 5.0 V ───┬─── ESP32 5V
              └─────────────┘             ├─── A7670G VCC
                     │                    │
                    GND ═════════════════╪═══ ESP32 GND
                                           ╪═══ A7670G GND
                                           │
                                      ┌────┴────┐
                                      │1000µF   │
                                      │ + −     │
                                      └─────────┘
```

### 5.4 Mermaid 接线图（可选渲染）

```mermaid
flowchart LR
    USB[USB Type-C 充电] --> TP4056
    BAT[603450 锂电池] --> TP4056
    TP4056 -->|OUT+ 3.7-4.2V| MT3608
    MT3608 -->|OUT+ 5.0V| BUS5V[5V 电源母线]
    MT3608 --> GND[GND 公共地]
    BUS5V --> ESP32[ESP32-S3 5V]
    BUS5V --> A7670[A7670G VCC]
    BUS5V --> CAP[1000µF 电容 +]
    CAP --> GND
    ESP32 -->|3.3V| LCD[ST7789]
    ESP32 -->|3.3V| CAM[OV5640]
    GND --- ESP32
    GND --- A7670
    GND --- LCD
    GND --- CAM
```

### 5.5 电源子系统分步操作

**步骤 5.1** — 在面包板或硬纸板上规划 **5 V 母线** 与 **GND 母线**，不要全部挤在 ESP32 排针上。

**步骤 5.2** — 焊接/拧紧 TP4056 与 MT3608 的进出线；暂时**不接** ESP32 与 A7670G。

**步骤 5.3** — 接入电池前，万用表测 TP4056 的 B+/B− 对 OUT+/OUT− 无异常短路（新电池约 3.7 V）。

**步骤 5.4** — 按 [第 8 章](#8-mt3608-调压步骤) 将 MT3608 **空载**调至 **5.0 V**。

**步骤 5.5** — 在 5 V 与 GND 之间焊接 **1000 µF 电容**（可先不焊 ESP32 侧）。

**步骤 5.6** — 给 ESP32 单独供电测试（5 V + GND），确认板载 3.3 V 正常。

**步骤 5.7** — 最后接入 A7670G 电源，观察 TP4056 / MT3608 是否异常发热。

---

## 6. 推荐引脚接线表

> **说明**：工作区中未发现已烧录固件/引脚头文件，下表基于 ESP32-S3 + OV5640（esp32-camera 常见 DVP 映射）+ ST7789 SPI + A7670G UART 的**常用接法**。  
> **若后续固件已定义 `pins.h` / `board_config.h`，以代码为准**；调整引脚后需同步修改固件并重新编译烧录。

### 6.1 引脚分配总览

| 功能 | 信号 | 推荐 GPIO | ESP32-S3 引脚位置提示 | 备注 |
|---|---|---|---|---|
| **ST7789** | MOSI (SDA) | **11** | 右侧排针 | SPI 数据（需与代码一致时可调整） |
| | SCLK (SCL) | **12** | 右侧排针 | SPI 时钟 |
| | CS | **10** | 右侧排针 | 片选，低有效 |
| | DC (RS) | **14** | 左侧排针 | 数据/命令 |
| | RST | **21** | 左侧排针 | 复位 |
| | BL (背光) | **47** | 底部/排针 | 高电平点亮；可 PWM |
| **OV5640** | XCLK | **15** | — | 主时钟 |
| | SIOD (SDA) | **4** | — | SCCB/I²C 数据 |
| | SIOC (SCL) | **5** | — | SCCB/I²C 时钟 |
| | D0～D7 | **8,9,10,11,12,13,16,17** | — | 8 位并行数据；**与屏幕 SPI 有冲突** |
| | VSYNC | **6** | — | 帧同步 |
| | HREF | **7** | — | 行有效 |
| | PCLK | **18** | — | 像素时钟 |
| | PWDN | **NC** | — | 未接则模块内部上拉 |
| | RESET | **NC** | — | 未接则模块内部上拉 |
| **A7670G** | ESP32 RX ← 模块 TX | **44** | UART RX | 交叉连接 |
| | ESP32 TX → 模块 RX | **43** | UART TX | 交叉连接 |
| | PWRKEY | **41** | 输出 | 开机：拉低 ≥1 s（以模块手册为准） |
| | RESET | **42** | 输出 | 可选，低复位 |
| | NET_STATUS | **2** | 输入 | 可选，读联网 LED 状态 |
| **按键** | BTN → GND | **0** | 带内部上拉 | 拍照键；**GPIO0 为 Strapping**，若影响启动可改 **1** 或 **3** |
| **电源** | 3.3 V | **3V3** | 排针 | 供屏幕、摄像头（注意总电流） |
| | GND | **GND** | 多根并联 | 共地 |

### 6.2 ⚠️ 重要：摄像头与屏幕引脚冲突

OV5640 的 **DVP 8 位并行** 会占用大量 GPIO，与上表 ST7789 的 **10/11/12** 存在重叠。常见解决方案：

1. **固件方案 A（推荐）**：使用 esp32-camera 官方 S3 引脚包，ST7789 改接 **35～40** 等空闲脚（需改代码）。
2. **固件方案 B**：摄像头与屏幕**分时复用**部分引脚（高级，需专用驱动）。
3. **硬件方案**：选用带独立 SPI 且引脚已隔离的 **摄像头+屏幕一体板**（本项目为分立模块，需软件协调）。

**折中推荐（供固件开发参考，需与代码一致时可调整）**：

| 功能 | 推荐 GPIO |
|---|---|
| ST7789 MOSI | **35** |
| ST7789 SCLK | **36** |
| ST7789 CS | **37** |
| ST7789 DC | **38** |
| ST7789 RST | **39** |
| ST7789 BL | **40** |
| OV5640 | 按 esp32-camera `camera_pins.h` 中 **ESP32S3_EYE** 或 **CUSTOM** 模板 |

### 6.3 ST7789 裸屏 12 Pin 常见定义

不同卖家线序可能不同，**以商家资料为准**；常见顺序如下（面向屏幕背面，从左到右）：

| Pin | 名称 | 接 ESP32 |
|-----|---|---|
| 1 | GND | GND |
| 2 | VCC | 3.3 V |
| 3 | SCL | SCLK |
| 4 | SDA | MOSI |
| 5 | RES | RST |
| 6 | DC | DC |
| 7 | CS | CS |
| 8 | BL | BL（3.3 V 或 GPIO） |
| 9～12 | NC/备用 | 不接 |

> 若线序不同：用万用表通断档对照商家图，**切勿**把 VCC 接到信号脚。

### 6.4 OV5640 模块

| 模块引脚 | 接 ESP32 |
|---|---|
| 3.3 V | 3.3 V |
| GND | GND |
| SCCB / I²C | SIOD→GPIO4, SIOC→GPIO5 |
| D0～D7, VSYNC, HREF, PCLK, XCLK | 见 6.1 表 |

排线：**金属触点朝向 PCB**，插入后扣紧卡扣。

### 6.5 A7670G MCore

| 模块引脚 | 接 ESP32 / 电源 |
|---|---|
| VCC / 5V | 5 V 母线（**不要**从 3.3 V 取电） |
| GND | GND |
| TXD | ESP32 **GPIO44 (RX)** |
| RXD | ESP32 **GPIO43 (TX)** |
| PWRKEY | GPIO41（通过 1kΩ 限流可选） |
| RESET | GPIO42 或悬空 |
| 天线 | FPC 天线贴盖非金属区 |

### 6.6 轻触开关（拍照键）

```
GPIO0 ──── 开关一脚
GND   ──── 开关另一脚（对角）
```

固件配置：`INPUT_PULLUP`，按下为 **LOW**。

### 6.7 完整接线示意（ASCII）

```
                    ┌──────────────── ESP32-S3-DevKitC-1 ────────────────┐
                    │                                                   │
   ST7789           │  3.3V ──────────────────── VCC                      │
   ┌────────┐       │  GND ──────────────────── GND                      │
   │ 240×240│◄──────┤  GPIO35-40 ───────────── SPI (MOSI/SCLK/CS/DC/RST/BL) │
   └────────┘       │                                                   │
                    │  GPIO4,5,6,7,8-18 ────── OV5640 DVP + SCCB       │
   OV5640           │                                                   │
   ┌────────┐       │  3.3V / GND ────────────── 摄像头供电             │
   │ AF     │◄──────┤                                                   │
   └────────┘       │  GPIO43 TX ─────────────► A7670 RXD                │
                    │  GPIO44 RX ◄──────────── A7670 TXD                │
   A7670G           │  GPIO41 ───────────────► PWRKEY                   │
   ┌────────┐       │  5V / GND ─────────────── 模块电源 + 1000µF      │
   │ 4G     │◄──────┤                                                   │
   └────────┘       │  GPIO0 ────[按键]─── GND                          │
                    │  5V ◄────────────────── MT3608 OUT+               │
                    └───────────────────────────────────────────────────┘
```

---

## 7. 分阶段组装步骤

### 阶段 0：规划与标注（约 30 分钟）

**步骤 0.1** — 打印或手抄 [第 6 章](#6-推荐引脚接线表) 引脚表，贴在工作台。

**步骤 0.2** — 给每根杜邦线贴标签（如 `SCL`、`MOSI`、`4G_TX`）。

**步骤 0.3** — 确认 3D 外壳已打印，USB 口、SIM 口、按键孔可试装（可先不放电子件）。

---

### 阶段 1：电源子系统（约 1 小时）

**步骤 1.1** — 按 [第 5 章](#5-电源子系统组装) 完成 TP4056 + 电池 + MT3608 + 电容。

**步骤 1.2** — 完成 [第 8 章](#8-mt3608-调压步骤) 调压，空载 **5.0 V**。

**步骤 1.3** — 仅连接 ESP32 的 **5V + GND**，上电测 3.3 V 引脚。

**验收**：ESP32 电源 LED 亮，无发热，万用表 3.3 V 正常。

---

### 阶段 2：裸板联调 — 屏幕（约 45 分钟）

**步骤 2.1** — ST7789 12 Pin 用杜邦线或焊接连至 ESP32（见 6.3）。

**步骤 2.2** — 烧录**屏幕测试固件**（Arduino `TFT_eSPI` 或厂家示例），确认 240×240 显示正常。

**步骤 2.3** — 背光不亮：交换 BL 接 **3.3 V** 常亮测试，或检查 GPIO 电平。

**验收**：纯色填充、文字、方向正确，无花屏/白屏。

---

### 阶段 3：裸板联调 — 摄像头（约 45 分钟）

**步骤 3.1** — 断电接 OV5640 排线。

**步骤 3.2** — 烧录 **esp32-camera** 示例（OV5640 自动检测或指定传感器）。

**步骤 3.3** — 串口查看是否识别 `OV5640`，能否输出 JPEG 大小 > 0。

**验收**：串口或网页看到清晰图像，自动对焦近距清晰。

---

### 阶段 4：裸板联调 — 4G（约 1 小时）

**步骤 4.1** — A7670G 接 5V/GND/UART/PWRKEY，**先不装壳**。

**步骤 4.2** — 按 [第 9 章](#9-a7670g-sim-卡安装与-at-联网测试) 插 SIM、发 AT 指令。

**步骤 4.3** — 确认 `AT+CPIN?` 返回 READY，`AT+CSQ` 有信号。

**验收**：`AT+CGATT=1` 附着成功，可 `AT+CIFSR` 或 PDP 激活（依运营商）。

---

### 阶段 5：裸板联调 — 按键（约 15 分钟）

**步骤 5.1** — GPIO0 与 GND 接轻触开关。

**步骤 5.2** — 烧录简单 GPIO 中断例程，串口打印按下/松开。

**验收**：每次按下串口有输出，无抖动可软件消抖。

---

### 阶段 6：模块叠加与理线（约 1～2 小时）

**步骤 6.1** — 将 ESP32、A7670、TP4056、MT3608 用双面胶或尼龙柱固定在壳内**非金属**区域。

**步骤 6.2** — 电池贴于壳体一侧，**避免**顶到摄像头排线；出线朝 TP4056。

**步骤 6.3** — 线束沿壳壁走线，避开 SIM 卡槽活动路径。

**步骤 6.4** — 用扎带/胶带分区：**电源线粗短**，**信号线远离天线**。

**步骤 6.5** — 可选：下壳四角 M3 柱（见 `generate_enclosure.py`）固定主控。

---

### 阶段 7：装壳（约 45 分钟）

**步骤 7.1** — 屏幕从内侧对准正面 **34×34 mm** 窗口，用胶固定 PCB/排针侧。

**步骤 7.2** — 摄像头对准 **36×24 mm** 窗口，镜头与孔同心。

**步骤 7.3** — 轻触开关对准右侧 **Ø12 mm** 孔，可加小帽提高手感。

**步骤 7.4** — TP4056 Type-C 与底部 **12×5 mm** 口对齐，可热熔胶限位。

**步骤 7.5** — A7670G SIM 槽与左侧 **16×3 mm** 口对齐。

**步骤 7.6** — FPC 天线贴于上盖内侧浅槽（**70×24 mm 区域**，非金属）。

**步骤 7.7** — 合盖前再次检查无短路、无顶线；上盖插扣后可选 M3 四角加固。

**验收**：外观孔位对齐，按键可按，SIM 可插拔，Type-C 可充电。

---

## 8. MT3608 调压步骤

### 8.1 所需条件

- 数字万用表（直流电压档）
- 电池或 TP4056 OUT 提供 **3.7～4.2 V** 输入（**勿用 USB 5 V 直灌 IN** 除非确认模块允许）
- **先断开** OUT 侧所有负载（ESP32、A7670G 均未接）

### 8.2 操作步骤

| 步骤 | 操作 | 预期结果 |
|---|---|---|
| 1 | MT3608 **IN+** 接 TP4056 **OUT+**，**IN−** 接 **OUT−** | 输入约 3.7～4.2 V |
| 2 | 万用表红表笔接 **OUT+**，黑表笔接 **OUT−** | 读数可能为 5 V 默认值或随机 |
| 3 | **顺时针/逆时针**缓慢旋转电位器，观察读数变化 | 找到可调范围 |
| 4 | 调至 **5.00 V ± 0.05 V** | 空载稳定 5.0 V |
| 5 | 接入 ESP32，再测 OUT 电压 | 负载下 ≥ 4.85 V 可接受 |
| 6 | 再接入 A7670G，发 `AT` 测试 | 电压不明显跌落；若 < 4.5 V 需检查线径/电容 |

### 8.3 注意事项

1. **先调压，后接负载** — 过高电压（> 5.5 V）可能损坏 ESP32 与 4G 模块。
2. 电位器为 **多圈** 时，微调耐心旋转。
3. 若输出电压**不受控**或输入发热 → 立即断电，检查 IN/OUT 是否接反。
4. 负载接入后压降大 → 加粗电源线、补 **1000 µF**、缩短路径。

---

## 9. A7670G SIM 卡安装与 AT 联网测试

### 9.1 SIM 卡安装

1. **完全断电**。
2. 确认卡为 **Nano SIM**（小卡），方向以卡槽丝印为准（缺角对齐）。
3. 从壳体左侧 **16×3 mm** 槽用镊子推入/弹出（弹簧卡槽）。
4. 插入时听到/感到卡扣到位。

### 9.2 硬件连接检查

| 项目 | 检查 |
|---|---|
| 5 V 供电 | 模块电源 LED 可能闪烁/常亮（视固件） |
| TX/RX | **交叉**：模块 TX → ESP32 RX(44)，模块 RX ← ESP32 TX(43) |
| GND | 与 ESP32 共地 |
| 天线 | FPC 已接，远离金属屏蔽 |

### 9.3 开机时序（PWRKEY）

多数 A7670 系列：

1. 上电后，**PWRKEY 拉低 ≥ 1 秒** 再释放 → 模块开机。
2. 或用 AT 工具自动拉 PWRKEY（固件实现）。

### 9.4 AT 测试（USB 串口监视器或独立 USB-TTL）

**串口参数**：115200, 8N1（部分默认 9600，无响应则切换）

| 序号 | 发送指令 | 期望响应 | 说明 |
|---|---|---|---|
| 1 | `AT` | `OK` | 通信正常 |
| 2 | `ATE0` | `OK` | 关闭回显 |
| 3 | `AT+CPIN?` | `+CPIN: READY` | SIM 就绪 |
| 4 | `AT+CSQ` | `+CSQ: xx,yy` | 信号；xx=99 表示无信号 |
| 5 | `AT+CREG?` | `0,1` 或 `0,5` | 网络注册 |
| 6 | `AT+CGATT=1` | `OK` | 附着 GPRS/PS |
| 7 | `AT+CGDCONT=1,"IP","APN"` | `OK` | APN 替换成运营商 APN |
| 8 | `AT+NETOPEN` 或 PDP 激活指令 | `OK` | 依 AT 手册版本 |

**常见 APN（中国大陆，以运营商客服为准）**：

| 运营商 | APN |
|---|-----|
| 中国移动 | `cmnet` 或 `cmiot`（物联卡） |
| 中国联通 | `3gnet` 或 `scuiot` |
| 中国电信 | `ctnet` 或 `ctnb` |

### 9.5 无响应排查

- 交换 TX/RX 再试
- 改波特率 9600 ↔ 115200
- 确认 PWRKEY 已开机
- 测 5 V 是否在 4.5～5.5 V

---

## 10. 各模块独立测试步骤

### 10.1 ST7789 屏幕

| 步骤 | 操作 | 通过标准 |
|---|---|---|
| 1 | 仅接 3.3V/GND/SPI 六线 | 无 smoke |
| 2 | 烧录 TFT 例程 | 有背光 |
| 3 | 显示红绿蓝 | 颜色正常 |
| 4 | 旋转测试 | 方向与外壳窗口一致 |

### 10.2 OV5640 摄像头

| 步骤 | 操作 | 通过标准 |
|---|---|---|
| 1 | 断电插排线 | 卡扣锁紧 |
| 2 | 烧录 CameraWebServer 或厂家例程 | 串口无 panic |
| 3 | 串口打印传感器名 OV5640 | 识别正确 |
| 4 | 拍照 JPEG | 文件 > 5 KB，非全黑/全绿 |
| 5 | 近距对焦 | 文字清晰 |

### 10.3 A7670G 4G

| 步骤 | 操作 | 通过标准 |
|---|---|---|
| 1 | 5V + 1000µF | 电压稳定 |
| 2 | AT 通信 | 返回 OK |
| 3 | SIM READY | CPIN READY |
| 4 | CSQ > 10 | 信号可用 |
| 5 | 注册网络 | CREG 1 或 5 |

### 10.4 按键

| 步骤 | 操作 | 通过标准 |
|---|---|---|
| 1 | 万用表通断档 | 按下导通 |
| 2 | GPIO 例程 | 按下串口输出 |
| 3 | 装壳后 | 孔位可按下 |

---

## 11. 3D 外壳安装要点

依据 `generate_enclosure.py` 与 `打印说明-给商家.txt`：

### 11.1 外壳规格摘要

| 项目 | 数值 |
|---|---|
| 外尺寸 | 100 × 100 × 100 mm |
| 下壳高度 | 92 mm |
| 上盖高度 | 8 mm |
| 壁厚 | 2 mm |
| 内腔 | ≈ 96 × 96 × 90 mm |
| 上盖配合 | 内唇 96 × 96 mm 插扣 |

### 11.2 开孔对照表

| 位置 | 尺寸 | 中心坐标 (X, Y, Z) | 安装要点 |
|---|---|---|---|
| **正面** 摄像头窗 | 36 × 24 mm | (30, 0, 70) | 镜头居中，避免塑料挡光 |
| **正面** 屏幕窗 | 34 × 34 mm | (79, 0, 52) | 屏幕应用泡棉压边防漏光 |
| **右面** 按键孔 | **Ø12 mm** | (100, 50, 28) | 轻触开关 + 可选键帽 |
| **左面** SIM 口 | 16 × 3 mm | (0, 18, 50) | 与 A7670G 卡槽对齐 |
| **底面** USB-C | 12 × 5 mm | (50, 10, 0) | TP4056 口对准，留插线空间 |
| **顶面** 挂绳孔 | Ø≈4.4 mm | (50, 8, 100) | 穿绳后打结在内侧 |
| **顶面内侧** 天线区 | 浅槽 70 × 24 mm | (50, 72, 顶) | FPC 天线贴此，**远离金属/电池** |

### 11.3 内部布局建议（俯视图 ASCII）

```
        Y（向里）
        ↑
        │    ┌─────────────────────────┐
        │    │ [摄像头窗]    [屏幕窗]   │  ← 正面 Y=0
        │    │                         │
        │    │   ESP32 + OV5640        │
        │    │         A7670G →SIM左侧│
        │    │  [电池]  TP4056+MT3608  │
        │    │      USB-C ↓ 底面       │
        └────┴─────────────────────────┴→ X（向右）
```

### 11.4 打印与材料

- 材料：**PETG** 或 **ABS**（耐温更好）；原型可用 PLA
- 填充：**20%～30%**，层高 **0.2 mm**
- **Scale = 100%**，勿缩放
- 下壳 USB 口可能需要**少量支撑**

### 11.5 固定建议

- 下壳四角 **M3 柱**（孔径 3.2 mm）可固定主控
- 电池用 **双面胶 + 泡棉** 固定，防止晃动撞击
- 合盖前确认 **FPC 天线不被夹断**

---

## 12. 整机上电与验收 Checklist

### 12.1 装壳前最后检查

- [ ] 无裸露导线短接
- [ ] 电池极性正确
- [ ] MT3608 输出 5.0 V
- [ ] 1000 µF 极性正确
- [ ] 摄像头排线、SIM 方向正确
- [ ] 天线已连接

### 12.2 首次整机通电

| 顺序 | 动作 | 观察 |
|---|---|---|
| 1 | 不接 USB 充电器，按电源/按键开机 | 屏幕亮、无异味 |
| 2 | 测 TP4056 / MT3608 温度 | 微温正常，烫手则断电 |
| 3 | 插入 USB 充电 | 充电 LED 正常 |
| 4 | 测试拍照 + 联网 | 功能完整 |

### 12.3 功能验收

- [ ] 屏幕显示正常，无漏光
- [ ] 摄像头成像清晰，对焦正常
- [ ] 按键触发拍照/扫题逻辑
- [ ] 4G 注册，可上传或 AT 拨测
- [ ] Type-C 充电正常，充满后截止
- [ ] 挂绳可靠，整机无 rattling
- [ ] 连续运行 30 分钟无重启、无过热

---

## 13. 常见问题排查表

| 现象 | 可能原因 | 处理步骤 |
|---|---|---|
| 上电无反应 | 电池没电/保护板锁死 | USB 充电 10 min；测 OUT 电压 |
| | MT3608 无输出 | 查 IN 电压；重新调 5 V |
| | ESP32 5V 未接 | 查 5V/GND 杜邦线 |
| ESP32 反复重启 | 5 V 过高/过低 | 万用表测 MT3608 OUT |
| | 4G 峰值压垮电源 | 加 1000µF、缩短线 |
| 屏幕白屏/花屏 | 线序错误 | 对照 6.3 节重接 |
| | SPI 引脚与代码不符 | 改引脚或改固件 |
| 屏幕无背光 | BL 未接或 GPIO 低 | BL 接 3.3V 或改 PWM |
| 摄像头未识别 | 排线反/松 | 重插排线 |
| | DVP 引脚冲突 | 按 6.2 节调整映射 |
| 图像全绿/黑 | 镜头膜未撕 | 撕膜 |
| | 光线不足 | 增加环境光 |
| AT 无响应 | TX/RX 未交叉 | 对调 TX/RX |
| | 波特率不对 | 试 9600/115200 |
| | 模块未开机 | PWRKEY 拉低 1 s |
| SIM 失败 | 卡未插好/APN 错 | 重插卡；查 APN |
| | 物联卡未激活 | 运营商平台激活 |
| CSQ=99 | 天线未接/金属遮挡 | 天线贴顶盖浅槽 |
| | 室内信号弱 | 靠窗测试 |
| 充电不进 | Type-C 口假 | 换线、换充电器 |
| | TP4056 损坏 | 测 USB 5V 到模块 |
| 整机发热 | 短路 | 立即断电，查线 |
| | 4G 长时间发射 | 检查信号弱导致高功率 |
| 合盖后按键无手感 | 开关未对准 | 重新固定位置 |
| | 键程不足 | 加键帽或垫片 |

---

## 14. 建议组装顺序时间线

适合**单日或两个半天**完成，含打印外壳等待时间另计。

| 阶段 | 内容 | 建议时长 | 累计 |
|---|---|---|---|
| **D0** | 3D 打印下单 / 等待 | — | — |
| **D1 上午** | 开箱验货（第 4 章） | 0.5 h | 0.5 h |
| | 电源子系统 + MT3608 调压（第 5、8 章） | 1.5 h | 2 h |
| **D1 下午** | ST7789 独立测试（10.1） | 1 h | 3 h |
| | OV5640 独立测试（10.2） | 1 h | 4 h |
| | 按键测试（10.4） | 0.25 h | 4.25 h |
| **D2 上午** | A7670G SIM + AT 测试（第 9 章） | 1.5 h | 5.75 h |
| | 全功能联调（固件集成） | 1 h | 6.75 h |
| **D2 下午** | 理线、固定、试装壳（第 7 阶段 6～7） | 2 h | 8.75 h |
| | 整机验收（第 12 章） | 0.5 h | **≈ 9～10 h** |

### 14.1 最小可行路径（赶时间）

若已有现成固件，可压缩为：

```
电源调压(1h) → 屏幕(0.5h) → 摄像头(0.5h) → 4G(1h) → 装壳(1.5h) ≈ 4.5h
```

### 14.2 不建议跳过的步骤

1. **MT3608 空载调压** — 跳过易烧板  
2. **分模块测试** — 跳过装壳后难以排查  
3. **1000 µF 电容** — 跳过 4G 易 brownout 重启  
4. **SIM/天线装壳前测试** — 跳过可能反复拆壳  

---

## 附录 A：ESP32-S3-DevKitC-1 快速参考

- **供电**：USB Type-C **或** 5V 引脚 + GND（推荐 5V 来自 MT3608）
- **3.3 V 输出**：排针 3V3，最大约 **700 mA**（含 PSRAM/Wi-Fi 峰值），**不宜**单独供 A7670G
- **Strapping 引脚**：GPIO0、GPIO3、GPIO45、GPIO46 — 外接电路避免强上下拉影响下载模式
- **烧录**：按住 **BOOT**，点 **RESET**，进入下载模式（部分板自动 USB 下载）

## 附录 B：文档修订记录

| 版本 | 日期 | 说明 |
|---|---|---|
| v1.0 | 2026-07-03 | 首版：基于已购 BOM + 3D 外壳 generate_enclosure.py |

---

**文档路径**：`/Users/linminhao/Documents/saoti-guajian-3d/ASSEMBLY.md`  
**相关文件**：同目录 `打印说明-给商家.txt`、`generate_enclosure.py`、`saoti_guajian_*.step`

如有固件引脚定义文件，请将其路径告知维护者，以便更新第 6 章为**与代码完全一致**的版本。

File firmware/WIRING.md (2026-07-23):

# 扫题挂件接线说明

固件引脚以 [`include/pins.h`](include/pins.h) 为准。接线前**断电**。

## 1. 屏幕 ST7789（微雪 1.3" / 同类 SPI）

| 屏幕 | ESP32 丝印 |
|---|---|
| VCC | 3V3 |
| GND | GND |
| DIN / MOSI | **1** |
| CLK / SCLK | **3** |
| CS | **38** |
| DC | **39** |
| RST | **40** |
| BL | **41** |

勿占用 GPIO 35–37（OPI PSRAM）。

## 2. 摄像头 OV5640（DVP）

供电：**3.3V + GND**（禁止 5V）。

| ESP 功能 | GPIO | 微雪 Camera Board (C) 丝印 | 正点原子常见丝印 |
|---|---|---|---|
| SIOD | 4 | SIOD | SDA / SIOD |
| SIOC | 5 | SIOC | SCL / SIOC |
| D0 | 6 | **D2** | D0 |
| D1 | 7 | **D3** | D1 |
| D2 | 8 | **D4** | D2 |
| D3 | 9 | **D5** | D3 |
| D4 | 10 | **D6** | D4 |
| D5 | 11 | **D7** | D5 |
| D6 | 12 | **D8** | D6 |
| D7 | 13 | **D9** | D7 |
| XCLK | 15 | XCLK | XCLK |
| VSYNC | 16 | VSYNC | VSYNC |
| HREF | 17 | HREF | HREF |
| PCLK | 18 | PCLK | PCLK |
| RST / PWDN | — | 可悬空 | 可悬空 |

微雪 C 型：约 35.7×23.9 mm，镜头两侧闪光灯，双排 2×9 针；数据脚是 **D2–D9**，不是 D0–D7。  
补光灯：模组内两侧 LED，经 **OV5640 STROBE → SI2302 MOSFET** 驱动（无需另接 GPIO）。  
固件会把 STROBE pad 配成输出并拉高（App「补光开」/ 串口 `FLASHON` / 拍照自动补光）。  
自动对焦：微雪 C 型需保证模组 **AF-VCC 接 3.3V**，固件会加载 AF 固件并在拍照前单次对焦。

### 装机朝向（正前方）

- **镜头必须朝外壳正面外**（与屏幕同面朝外）；排针在板短边，杜邦出左侧（−X）。
- 勿把板旋转 180°：否则镜头对不准前壳圆孔，画面会像斜拍/被壁挡住。
- 固件默认 `vflip=1`。若上下仍反：串口发 `CAMFLIP`；左右反发 `CAMMIRROR`。

## 3. 4G 模块 FS-MCore-A7670G（全球版 AT）

| 模块丝印 | ESP32 | 说明 |
|---|---|---|
| VIN | **独立 5V ≥2A** | 不要只靠开发板 USB 硬撑 |
| GND | GND | 与 ESP **共地** |
| RX | **21** | ← ESP TX（交叉） |
| TX | **2** | → ESP RX（交叉） |
| PEN | **48**（或直接 3V3） | **使能，必须常高**；固件上电拉高 GPIO48 |
| PWK | **47** | 开机键；固件拉低约 1.2s |
| NET | **悬空** | 不要接到 GPIO2（会和 UART RX 冲突） |

注意：

- TX/RX **交叉**；不要接到板子标 USB 的 `TX`/`RX`（那是 USB 口）。
- **旧店家表作废**：`模TX→47`、`PWK→41`、`NET→2` 会与当前屏/串口冲突，勿再按那个接。
- 蓝灯亮才算模块开机；只有红灯通常还没起来。

### 3.1 先用 FreeAT 验证模块本身（强烈建议）

商家工具 `FreeAT_2.3.0.exe` 是 **Windows** 串口 AT 助手（Mac 不能直接双击跑）。

1. Windows 电脑安装模块 USB 驱动（店家资料包）。
2. 模块 **Type-C USB** 插电脑；**VIN 仍建议另接 5V≥2A**，GND 共地。
3. **PEN 接 3.3V**（或接 ESP 的 3V3），必要时手动短接 **PWK** 到 GND 约 1～2 秒开机，等蓝灯。
4. 打开 FreeAT → 选 COM 口 → **115200 8N1** → 发送 `AT`，应回 `OK`。

| FreeAT 结果 | 含义 | 下一步 |
|---|---|---|
| USB 有 `OK` | 模块本身正常 | 再按上表接 ESP UART |
| USB 也无响应 | 供电/开机/驱动问题 | 先别查 ESP 固件 |

Mac 上等价做法：烧录 `esp32s3-modem-bridge`，用串口监视器发 `AT`。

## 4. 电池电量（分压 → GPIO14）

开发板**不能**直接测电池电压，需两只电阻分压后接 ADC：

```text
电池正极 B+ ── 100kΩ ──┬── GPIO14（ESP 丝印 14）
                        │
                       100kΩ
                        │
                       GND
```

| 参数 | 值 |
|---|-----|
| 分压比 | 2（固件 `BAT_DIVIDER_RATIO`） |
| 空电 / 满电 | 3.30V / 4.20V（锂电） |
| 显示 | 屏左上角 `85%`；未接线显示 `--%` |

注意：电阻接到**电池端（升压前）**，不要接到 5V 升压后。两电阻建议 ≥100k，减小耗电。

**为何用 ADC2（GPIO14）：** ESP32-S3 的 ADC1（GPIO1–10）已被 LCD/摄像头占满，只能用 ADC2。WiFi SoftAP（答案页热点）开启时 ADC2 会受射频干扰，固件会**冻结电量采样**（保持上次读数），热点关闭后再更新。若以后改板，优先把电池分压迁到空闲的 ADC1 脚。

## 5. 按键（2 位独立按键模块）

实物：[天猫 2 位独立按键模块](https://detail.tmall.com/item.htm?id=610117189167)（电子积木双大方键板，**不是**单颗 6×6）。

常见排针：`GND` / `KEY1` / `KEY2`（按下拉低；ESP `INPUT_PULLUP`）。若板子有 `VCC`，接 **3V3**。

| 模块 | ESP | 功能 |
|---|-----|---|
| KEY1 | **GPIO0**（丝印 0 / BOOT） | 短按扫题 |
| KEY2 | **GPIO42** | 短按切换 **唤醒 / 休眠** |
| GND | GND | 共地 |
| （可选）板载 BOOT | — | 与 KEY1 同脚，后壳腰圆孔备用 |

### 3D 打印外壳要点（v7.5）

- 后壳**左侧壁**：双键方窗 + 内侧整板凹座（口袋约 42×24，键距 15.5）。
- ESP USB 仍出**右侧壁**；板载 BOOT 腰圆孔保留。
- 上电瞬间勿按住 GPIO0（会进下载模式）。

电源开关仍用电池正极拨动开关，与拍照键分开。

可打印文件：[`hardware/case/PRINT.md`](../hardware/case/PRINT.md)（`stl/saoti_front.stl` + `saoti_back.stl`）。

## 6. 语音 TTS（UART 中文播报）

推荐 **XFS5152 / SYN6288 同类串口语音合成板 + 小喇叭**（播报扫题答案，非语音识别）。

| 模块 | ESP | 说明 |
|---|-----|---|
| RX | **GPIO45**（ESP TX → 模 RX） | 固件 `Serial1`，默认 9600 |
| BUSY（可选） | **GPIO46** | 忙时高电平；不接则按字数延时分句 |
| GND | GND | 共地 |
| VCC | **按模块标称**（多为 5V 或 3.3V） | **勿与摄像头抢弱 3V3**；喇叭接模块功放输出 |

默认固件 `TTS_UTF8=1`（XFS5152 UTF-8）。若是纯 SYN6288 且只要 GBK，编译加 `-DTTS_UTF8=0` 并自行保证文本编码。

串口调试：`SAY=你好` 播报；`TTSSTOP` 停止；`TTS` 查状态。解题成功后自动播报答案；KEY2 休眠会停播。

无模块时可保持接线空置；或 `-DTTS_ENABLE=0` 关掉。

## 7. SoftAP

- SSID：`SaotiCam` / 密码：`saoti1234`
- 控制台：`http://192.168.4.1/`
- 答案：`/answer` · 测 AI：`/test` · 状态：`/status`

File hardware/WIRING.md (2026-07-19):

# 扫题挂件接线说明

固件引脚以 [`include/pins.h`](include/pins.h) 为准。接线前**断电**。

## 1. 屏幕 ST7789（微雪 1.3" / 同类 SPI）

| 屏幕 | ESP32 丝印 |
|---|---|
| VCC | 3V3 |
| GND | GND |
| DIN / MOSI | **1** |
| CLK / SCLK | **3** |
| CS | **38** |
| DC | **39** |
| RST | **40** |
| BL | **41** |

勿占用 GPIO 35–37（OPI PSRAM）。

## 2. 摄像头 OV5640（DVP）

供电：**3.3V + GND**（禁止 5V）。

| ESP 功能 | GPIO | 微雪 Camera Board (C) 丝印 | 正点原子常见丝印 |
|---|---|---|---|
| SIOD | 4 | SIOD | SDA / SIOD |
| SIOC | 5 | SIOC | SCL / SIOC |
| D0 | 6 | **D2** | D0 |
| D1 | 7 | **D3** | D1 |
| D2 | 8 | **D4** | D2 |
| D3 | 9 | **D5** | D3 |
| D4 | 10 | **D6** | D4 |
| D5 | 11 | **D7** | D5 |
| D6 | 12 | **D8** | D6 |
| D7 | 13 | **D9** | D7 |
| XCLK | 15 | XCLK | XCLK |
| VSYNC | 16 | VSYNC | VSYNC |
| HREF | 17 | HREF | HREF |
| PCLK | 18 | PCLK | PCLK |
| RST / PWDN | — | 可悬空 | 可悬空 |

微雪 C 型：约 35.7×23.9 mm，镜头两侧闪光灯，双排 2×9 针；数据脚是 **D2–D9**，不是 D0–D7。  
补光灯由模组内 **OV5640 STROBE** 驱动（无需另接 GPIO）；固件拍照前测光偏暗时自动点亮。  
自动对焦：微雪 C 型需保证模组 **AF-VCC（约第 24 脚）接 3.3V**，固件会加载 AF 固件并在拍照前单次对焦。

### 装机朝向（正前方）

- **镜头必须朝外壳正面外**（与屏幕同面朝外）；排针在板短边，杜邦出左侧（−X）。
- 勿把板旋转 180°：否则镜头对不准前壳圆孔，画面会像斜拍/被壁挡住。
- 固件默认 `vflip=1`。若上下仍反：串口发 `CAMFLIP`；左右反发 `CAMMIRROR`。

## 3. 4G 模块 FS-MCore-A7670G（全球版 LT）

| 模块丝印 | ESP32 | 说明 |
|---|---|---|
| VIN | **独立 5V ≥2A** | 不要只靠开发板 USB 硬撑 |
| GND | GND | 与 ESP **共地** |
| RX | **21** | ← ESP TX（交叉） |
| TX | **2** | → ESP RX（交叉） |
| PEN | **48**（或直接 3V3） | **使能，必须常高**；固件上电拉高 GPIO48 |
| PWK | **47** | 开机键；固件拉低约 1.2s |
| NET | **悬空** | 不要接到 GPIO2（会和 UART RX 冲突） |

注意：

- TX/RX **交叉**；不要接到板子标 USB 的 `TX`/`RX`（那是 USB 口）。
- **旧店家表作废**：`模TX→47`、`PWK→41`、`NET→2` 会与当前屏/串口冲突，勿再按那个接。
- 蓝灯亮才算模块开机；只有红灯通常还没起来。

### 3.1 先用 FreeAT 验证模块本身（强烈建议）

商家工具 `FreeAT_2.3.0.exe` 是 **Windows** 串口 AT 助手（Mac 不能直接双击跑）。

1. Windows 电脑安装模块 USB 驱动（店家资料包）。
2. 模块 **Type-C USB** 插电脑；**VIN 仍建议另接 5V≥2A**，GND 共地。
3. **PEN 接 3.3V**（或接 ESP 的 3V3），必要时手动短接 **PWK** 到 GND 约 1～2 秒开机，等蓝灯。
4. 打开 FreeAT → 选 COM 口 → **115200 8N1** → 发送 `AT`，应回 `OK`。

| FreeAT 结果 | 含义 | 下一步 |
|---|---|---|
| USB 有 `OK` | 模块本身正常 | 再按上表接 ESP UART |
| USB 也无响应 | 供电/开机/驱动问题 | 先别查 ESP 固件 |

Mac 上等价做法：烧录 `esp32s3-modem-bridge`，用串口监视器发 `AT`。

## 4. 电池电量（分压 → GPIO14）

开发板**不能**直接测电池电压，需两只电阻分压后接 ADC：

```text
电池正极 B+ ── 100kΩ ──┬── GPIO14（ESP 丝印 14）
                        │
                       100kΩ
                        │
                       GND
```

| 参数 | 值 |
|---|-----|
| 分压比 | 2（固件 `BAT_DIVIDER_RATIO`） |
| 空电 / 满电 | 3.30V / 4.20V（锂电） |
| 显示 | 屏左上角 `85%`；未接线显示 `--%` |

注意：电阻接到**电池端（升压前）**，不要接到 5V 升压后。两电阻建议 ≥100k，减小耗电。

**为何用 ADC2（GPIO14）：** ESP32-S3 的 ADC1（GPIO1–10）已被 LCD/摄像头占满，只能用 ADC2。WiFi SoftAP（答案页热点）开启时 ADC2 会受射频干扰，固件会**冻结电量采样**（保持上次读数），热点关闭后再更新。若以后改板，优先把电池分压迁到空闲的 ADC1 脚。

## 5. 按键（2 位独立按键模块）

实物：[天猫 2 位独立按键模块](https://detail.tmall.com/item.htm?id=610117189167)（电子积木双大方键板，**不是**单颗 6×6）。

常见排针：`GND` / `KEY1` / `KEY2`（按下拉低；ESP `INPUT_PULLUP`）。若板子有 `VCC`，接 **3V3**。

| 模块 | ESP | 功能 |
|---|-----|---|
| KEY1 | **GPIO0**（丝印 0 / BOOT） | 短按扫题；长按≈3s 测 AI |
| KEY2 | **GPIO42** | 短按固定题图测 AI |
| GND | GND | 共地 |
| （可选）板载 BOOT | — | 与 KEY1 同脚，后壳腰圆孔备用 |

### 3D 打印外壳要点（v7.5）

- 后壳**左侧壁**：双键方窗 + 内侧整板凹座（口袋约 42×24，键距 15.5）。
- ESP USB 仍出**右侧壁**；板载 BOOT 腰圆孔保留。
- 上电瞬间勿按住 GPIO0（会进下载模式）。

电源开关仍用电池正极拨动开关，与拍照键分开。

可打印文件：[`case/PRINT.md`](case/PRINT.md)、[`case/COMPONENTS.md`](case/COMPONENTS.md)。

## 6. SoftAP

- SSID：`SaotiCam` / 密码：`saoti1234`
- 控制台：`http://192.168.4.1/`
- 答案：`/answer` · 测 AI：`/test` · 状态：`/status`

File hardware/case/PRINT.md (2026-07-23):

# 扫题挂件外壳 v7.36 — 全检修订

先读 [`COMPONENTS.md`](COMPONENTS.md)。

- v7.35：止口四角留壁 0.8 mm
- **v7.36**：全检通过；卡勾尖外壁余量提到 **≥0.5 mm**

外廓 **76×110×58**。只交 `stl/saoti_front.stl`、`stl/saoti_back.stl`。

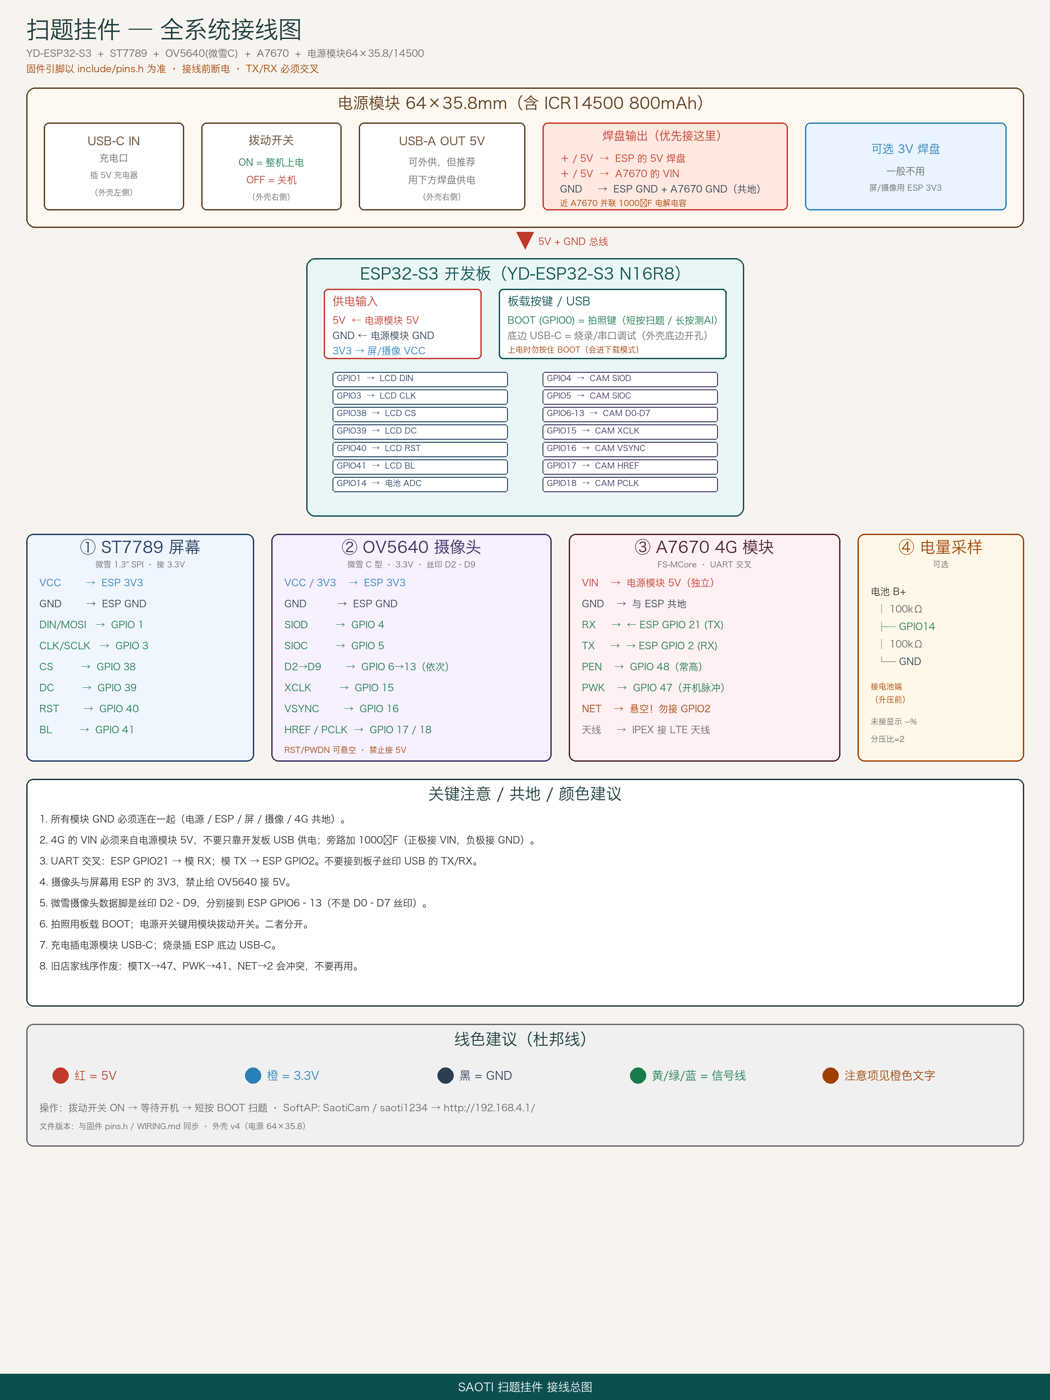
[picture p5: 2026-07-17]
firmware/docs/wiring_all.png

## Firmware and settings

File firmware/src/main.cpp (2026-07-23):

#include "config.h"
#include "pins.h"
#include "app_control.h"
#include "service_tick.h"

#include <vector>
#include "modules/answer_ap.h"
#include "modules/battery.h"
#include "modules/button.h"
#include "modules/camera.h"
#include "modules/display.h"
#include "modules/modem.h"
#include "modules/stream_server.h"
#include "modules/usb_stream.h"
#include "modules/solver.h"
#include "modules/ble_gatt.h"
#include "modules/tts.h"
#include "serial_lock.h"
#include "test_question_jpeg.h"

#if !USE_MOCK_CAMERA
#include <Wire.h>
#endif
#if USE_WIFI_FALLBACK || STREAM_ENABLE
#include <WiFi.h>
#endif

namespace {

enum class AppState {
  Idle,
  Capturing,
  Uploading,
  ShowResult,
};

AppState state = AppState::Idle;
Display display;
Camera camera;
Modem modem;
Button button;
Button button2;
StreamServer streamServer;
UsbStream usbStream;
Solver solver;

uint32_t result_until = 0;
uint32_t error_until = 0;
uint32_t last_ui_activity = 0;
bool system_ready = false;
bool colorbarOn = false;

volatile bool gPendingFixedAi = false;
volatile bool gPendingCapture = false;
volatile bool gPendingWake = false;
volatile bool gPendingThumb = false;
volatile bool gPendingFlash = false;
volatile bool gPendingFlashOn = false;
volatile bool gTorchOn = false;  // 补光常亮时禁止外设休眠
volatile bool gPipelineBusyFlag = false;

void setState(AppState next) {
  state = next;
  const char* phase = "idle";
  switch (next) {
    case AppState::Capturing:
      phase = "capturing";
      break;
    case AppState::Uploading:
      phase = "uploading";
      break;
    case AppState::ShowResult:
      phase = "result";
      break;
    case AppState::Idle:
    default:
      phase = "idle";
      break;
  }
  ble_gatt::setPhase(phase);
}

const char* uiError(const char* err) {
  if (!err || !err[0]) {
    return "出错了，请重试";
  }
  if (strstr(err, "wake")) {
    return "唤醒失败";
  }
  if (strstr(err, "camera offline") || strstr(err, "not ready")) {
    return "摄像头未就绪";
  }
  if (strstr(err, "capture") || strstr(err, "fb_get")) {
    return "拍照失败";
  }
  if (strstr(err, "bad image") || strstr(err, "too small") ||
      strstr(err, "1210")) {
    return "图片无效，请重拍";
  }
  if (strstr(err, "retake") || strstr(err, "too large") ||
      strstr(err, "jpeg too large")) {
    return "图片太大，请靠近重拍";
  }
  if (strstr(err, "4G") || strstr(err, "network") || strstr(err, "modem")) {
    return "网络未就绪";
  }
  if (strstr(err, "busy") || strstr(err, "429")) {
    return "模型繁忙，请稍后再试";
  }
  if (strstr(err, "free tier") || strstr(err, "exhausted")) {
    return "免费额度用尽";
  }
  if (strstr(err, "http") || strstr(err, "TLS") || strstr(err, "ai ")) {
    return "AI 请求失败";
  }
  if (strstr(err, "parse")) {
    return "答案解析失败";
  }
  if (strstr(err, "API key") || strstr(err, "Zhipu") || strstr(err, "set API")) {
    return "请配置智谱 API Key";
  }
  // 已是中文则原样显示
  for (const char* p = err; *p; ++p) {
    if (static_cast<unsigned char>(*p) >= 0x80) {
      return err;
    }
  }
  return "出错了，请重试";
}

void noteUiActivity() {
  last_ui_activity = millis();
  display.setBacklight(true);
}

bool periphSleeping() {
  return camera.isSleeping() || modem.radioSleeping();
}

void enterPeriphSleep() {
  if (answer_ap::active()) {
    return;
  }
#if USB_STREAM_ENABLE
  // USB 推流中 deinit 相机会与 usb_stream 任务抢 fb → 挂死/黑屏
  if (usbStream.isActive()) {
    return;
  }
#endif
  if (periphSleeping()) {
    return;
  }
  Serial.println("[PWR] peripheral sleep (cam + modem CFUN=0)");
  tts::stop();
#if USB_STREAM_ENABLE
  usbStream.setActive(false);
#endif
#if !USE_MOCK_CAMERA
  camera.setStreamingPaused(true);
#endif
  delay(50);
  camera.sleep();
#if !USE_MOCK_CAMERA
  camera.setStreamingPaused(false);
#endif
  modem.sleepRadio();
  display.setBacklight(false);
}

// 前向声明
void showScanStep(int step, const char* tip = nullptr);
void showBootSelfCheck(int step, const char* tip);
void showWakeSelfCheck(int step, const char* tip);
void refreshBattBadge();
void refreshNetBadge(const char* forceVia = nullptr);

// 开机 / 休眠唤醒 分步自检（屏上可见）
constexpr int kBootCheckCount = 5;
const char* const kBootCheckSteps[kBootCheckCount] = {
    "摄像头", "蓝牙广播", "4G 模组", "蜂窝网络", "电池",
};
constexpr int kWakeCheckCount = 6;
const char* const kWakeCheckSteps[kWakeCheckCount] = {
    "唤醒摄像头", "检测摄像头", "检测蓝牙", "唤醒 4G", "检测网络", "检测电池",
};

void showBootSelfCheck(int step, const char* tip) {
  noteUiActivity();
  refreshBattBadge();
  refreshNetBadge();
  display.setBacklight(true);
  display.showSteps(step, kBootCheckCount, kBootCheckSteps, tip);
}

void showWakeSelfCheck(int step, const char* tip) {
  noteUiActivity();
  refreshBattBadge();
  refreshNetBadge();
  display.setBacklight(true);
  display.showSteps(step, kWakeCheckCount, kWakeCheckSteps, tip);
}

// 蓝牙自检：重新广播，并在 tip 里带上可搜索的名字
bool runBleSelfCheck(void (*showStep)(int, const char*), int stepIndex) {
#if !BLE_GATT_ENABLE
  showStep(stepIndex, "蓝牙未编译");
  delay(200);
  return false;
#else
  showStep(stepIndex, "正在检查蓝牙广播…");
  const bool ok = ble_gatt::selfCheck();
  if (!ok) {
    showStep(stepIndex, "蓝牙启动失败");
    delay(700);
    return false;
  }
  char tip[48];
  snprintf(tip, sizeof(tip), "可搜 %s", ble_gatt::advName());
  showStep(stepIndex, tip);
  Serial.printf("[BLE] check ok — search App for %s (not in 系统蓝牙列表)\n",
                ble_gatt::advName());
  delay(500);
  return true;
#endif
}

bool wakePeripherals(const char* reason, bool quietUi = false) {
  noteUiActivity();
  const bool needCam = camera.isSleeping();
  const bool needModem = modem.radioSleeping();
  // 外设已醒：已连接则不要重广播（会弄断 iPhone）；未连接再自检广播
  if (!needCam && !needModem) {
    display.setBacklight(true);
    Serial.printf("[PWR] light selfcheck ble (%s quiet=%d)\n",
                  reason ? reason : "?", quietUi ? 1 : 0);
#if BLE_GATT_ENABLE
    if (ble_gatt::isConnected()) {
      return true;
    }
#endif
    if (quietUi) {
      // 手机扫题中途：勿弹自检页，静默保活广播即可
      ble_gatt::restartAdvertising();
      return ble_gatt::isReady();
    }
    return runBleSelfCheck(showWakeSelfCheck, 3);
  }

  // 手机已连接时的安静唤醒：只拉起外设，不走 6 步自检屏（避免「又从头开始」）
  if (quietUi) {
    Serial.printf("[PWR] quiet wake (%s) cam=%d modem=%d\n",
                  reason ? reason : "?", needCam ? 1 : 0, needModem ? 1 : 0);
    display.setBacklight(true);
    bool ok = true;
    if (needCam && !camera.wake()) {
      Serial.println("[PWR] quiet wake: camera fail");
      ok = false;
    }
    if (needModem && !modem.wakeRadio()) {
      Serial.println("[PWR] quiet wake: modem fail");
      ok = false;
    }
    if (ok && camera.isReady() && !camera.probeFrame()) {
      Serial.println("[PWR] quiet wake: cam probe fail — recover");
      ok = camera.wake() && camera.probeFrame();
    }
    if (ok && modem.isCellReady()) {
      if (!modem.ensureCellNetwork()) {
        Serial.println("[PWR] quiet wake: cell network fail");
        ok = false;
      }
    } else if (ok && needModem) {
      // 射频刚开，给一点时间再检；失败仍返回 false 让 App 侧看到错误
      serviceDelay(800);
      if (!modem.ensureCellNetwork()) {
        Serial.println("[PWR] quiet wake: cell network fail after wake");
        ok = false;
      }
    }
    refreshNetBadge();
    refreshBattBadge();
    Serial.printf("[PWR] quiet wake done ok=%d\n", ok ? 1 : 0);
    return ok;
  }

  Serial.printf("[PWR] wake+selfcheck (%s)...\n", reason ? reason : "?");
  display.setBacklight(true);
  bool ok = true;

  // 1) 摄像头
  showWakeSelfCheck(1, needCam ? "正在重新启动摄像头…" : "摄像头已就绪");
  if (needCam) {
    if (!camera.wake()) {
      ok = false;
      showWakeSelfCheck(1, "摄像头唤醒失败");
      delay(600);
    }
  }

  // 2) 摄像头探测
  showWakeSelfCheck(2, "正在抓取测试帧…");
  if (camera.isReady()) {
    if (!camera.probeFrame()) {
      Serial.println("[PWR] cam probe fail — recover once");
      showWakeSelfCheck(2, "摄像头异常，正在恢复…");
      if (!camera.wake() || !camera.probeFrame()) {
        ok = false;
        showWakeSelfCheck(2, "摄像头自检失败");
        delay(600);
      } else {
        showWakeSelfCheck(2, "摄像头恢复成功");
        delay(300);
      }
    } else {
      showWakeSelfCheck(2, "摄像头正常");
      delay(200);
    }
  } else {
    ok = false;
    showWakeSelfCheck(2, "摄像头未就绪");
    delay(600);
  }

  // 3) 蓝牙：已连接则跳过重广播（否则 iPhone 会断链）
#if BLE_GATT_ENABLE
  if (ble_gatt::isConnected()) {
    showWakeSelfCheck(3, "蓝牙已连接");
    delay(150);
  } else if (!runBleSelfCheck(showWakeSelfCheck, 3)) {
    ok = false;
  }
#else
  showWakeSelfCheck(3, "蓝牙未编译");
#endif

  // 4) 4G 射频
  showWakeSelfCheck(4, needModem ? "正在打开 4G 射频…" : "4G 已就绪");
  if (needModem) {
    if (!modem.wakeRadio()) {
      ok = false;
      showWakeSelfCheck(4, "4G 唤醒失败");
      delay(600);
    } else {
      showWakeSelfCheck(4, "4G 射频已打开");
      delay(200);
    }
  }

  // 5) 网络
  showWakeSelfCheck(5, "正在检查蜂窝网络…");
  if (modem.isCellReady()) {
    if (!modem.ensureCellNetwork()) {
      ok = false;
      showWakeSelfCheck(5, "网络未就绪，稍后重试");
      delay(600);
    } else {
      char tip[40];
      snprintf(tip, sizeof(tip), "网络正常 CSQ=%d", modem.lastCsq());
      showWakeSelfCheck(5, tip);
      delay(250);
    }
  } else {
    ok = false;
    showWakeSelfCheck(5, "模组未就绪");
    delay(600);
  }
  refreshNetBadge();
  // 仅未连接时重广播（connected 时 restartAdvertising 会直接跳过）
  ble_gatt::restartAdvertising();

  // 6) 电池
  showWakeSelfCheck(6, "正在读取电量…");
  battery::setAdcFrozen(false);
  (void)battery::voltage();
  refreshBattBadge();
  {
    char tip[40];
    snprintf(tip, sizeof(tip), "电量 %s%s", battery::label(),
             battery::isCharging() ? " · 充电中" : "");
    showWakeSelfCheck(6, tip);
    delay(300);
  }

  Serial.printf("[PWR] selfcheck done ok=%d\n", ok ? 1 : 0);
  return ok;
}

void presentAnswer(const char* answer) {
  noteUiActivity();
  const bool apOk = answer_ap::start();
  if (apOk) {
    battery::setAdcFrozen(true);
    char hint[40];
    snprintf(hint, sizeof(hint), "全文 %s/answer", answer_ap::ip().c_str());
    display.setAnswerApHint(hint);
  } else {
    display.setAnswerApHint("完整答案可看串口输出");
  }
  display.showAnswer(answer);
  result_until = millis() + RESULT_HOLD_MS;
  setState(AppState::ShowResult);
  ble_gatt::notifyAnswerChanged();
  tts::speak(answer);
}

void showErrorHold(const char* message) {
  noteUiActivity();
  answer_ap::stop();
  battery::setAdcFrozen(false);
  display.show(UiScreen::Error, uiError(message));
  error_until = millis() + ERROR_HOLD_MS;
  setState(AppState::Idle);
}

const char* idleHint() {
  static char buf[24];
#if BLE_GATT_ENABLE
  if (ble_gatt::isReady() && ble_gatt::advName()[0]) {
    // 空闲主行只显示蓝牙名，副行由显示层提示「请用 App」
    snprintf(buf, sizeof(buf), "%s", ble_gatt::advName());
    return buf;
  }
#endif
  return camera.isReady() ? "KEY1扫题 KEY2休眠" : "KEY1测AI KEY2休眠";
}

// 顶部网络条：空闲显示可用链路；扫题时显示实际使用的通道
void refreshNetBadge(const char* forceVia) {
  if (forceVia && forceVia[0]) {
    if (strstr(forceVia, "WiFi") || strstr(forceVia, "wifi")) {
      display.setNetBadge("WiFi");
    } else {
      display.setNetBadge("4G");
    }
    return;
  }
#if NET_CELL_ONLY || !USE_WIFI_FALLBACK
  if (modem.radioSleeping()) {
    display.setNetBadge("4G休眠");
  } else {
    display.setNetBadge(modem.isCellReady() ? "4G" : "无网");
  }
#else
  if (modem.radioSleeping() && !modem.isWifiReady()) {
    display.setNetBadge("休眠");
  } else {
    const bool w = modem.isWifiReady();
    const bool c = modem.isCellReady() && !modem.radioSleeping();
    if (w && c) {
      display.setNetBadge("双网");
    } else if (w) {
      display.setNetBadge("WiFi");
    } else if (c) {
      display.setNetBadge("4G");
    } else {
      display.setNetBadge("无网");
    }
  }
#endif
}

void refreshBattBadge() {
  display.setBattBadge(battery::label());
  display.setCharging(battery::isCharging());
}

// 扫题分步（屏上中文进度）
constexpr int kScanStepCount = 6;
const char* const kScanSteps[kScanStepCount] = {
    "唤醒设备", "正在拍照", "检查图片", "连接网络", "上传题目", "AI 解答中",
};

void showScanStep(int step, const char* tip) {
  noteUiActivity();
  refreshBattBadge();
  if (step >= 4) {
    refreshNetBadge("4G");
  } else {
    refreshNetBadge();
  }
  display.showSteps(step, kScanStepCount, kScanSteps, tip);
}

void showIdle() {
  noteUiActivity();
  error_until = 0;
  answer_ap::stop();
  battery::setAdcFrozen(false);
  refreshBattBadge();
  refreshNetBadge();
  display.show(UiScreen::Idle, idleHint());
}

bool appPipelineBusy() {
  return gPipelineBusyFlag || state == AppState::Capturing ||
         state == AppState::Uploading;
}

struct PipelineGuard {
  PipelineGuard() {
    gPipelineBusyFlag = true;
    gPendingCapture = false;
    gPendingFixedAi = false;
  }
  ~PipelineGuard() { gPipelineBusyFlag = false; }
};

bool modemCommandsAllowed() {
  if (appPipelineBusy()) {
    return false;
  }
#if USB_STREAM_ENABLE
  if (usbStream.isActive()) {
    return false;
  }
#endif
  return true;
}

void preparePeripheralsForCamera() {
  prepareModemPins();
#if !USE_MOCK_CAMERA
  Wire.end();
#endif
}

#if !USE_MOCK_CAMERA
void i2cScan(int sda, int scl, const char* label) {
  Wire.end();
  delay(10);
  Wire.begin(sda, scl);
  Wire.setClock(100000);
  Serial.printf("[DIAG] I2C scan %s (SDA=GPIO%d SCL=GPIO%d):\n", label, sda, scl);
  int count = 0;
  for (uint8_t addr = 1; addr < 127; ++addr) {
    Wire.beginTransmission(addr);
    if (Wire.endTransmission() == 0) {
      Serial.printf("[DIAG]   0x%02X", addr);
      if (addr == 0x3C) {
        Serial.print(" <- OV5640 SCCB");
      }
      Serial.println();
      ++count;
    }
  }
  if (count == 0) {
    Serial.println("[DIAG]   (no devices — check 3.3V/GND/SDA/SCL/排线)");
  }
}

void runHardwareDiag() {
  Serial.println("[DIAG] ---- hardware probe ----");
  Serial.printf("[DIAG] camera: SDA=%d SCL=%d XCLK=%d D0-7=%d-%d\n",
                pins::CAM_SIOD, pins::CAM_SIOC, pins::CAM_XCLK, pins::CAM_D0,
                pins::CAM_D7);
  Serial.println("[DIAG] Waveshare C silk: D2..D9 -> ESP CAM_D0..D7 (GPIO6..13)");
  Serial.printf("[DIAG] 4G: ESP-TX=%d -> 模RX | ESP-RX=%d <- 模TX\n",
                pins::MODEM_TX, pins::MODEM_RX);
  Serial.println("[DIAG] 4G: VIN独立5V≥2A+共地 | PEN→48常高 | PWK→47脉冲 | 蓝灯=开机");
  i2cScan(pins::CAM_SIOD, pins::CAM_SIOC, "normal");
  i2cScan(pins::CAM_SIOC, pins::CAM_SIOD, "swapped");
  Serial.println("[DIAG] ---- end probe ----");
}
#endif
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
void loop() {
  button.update();
  button2.update();
  ble_gatt::loop();
  tts::loop();

  if (appConsumeWakeRequest()) {
    (void)wakePeripherals("ble");
  }
  bool flashOn = false;
  if (appConsumeFlashRequest(&flashOn)) {
#if !USE_MOCK_CAMERA
    noteUiActivity();
    // 只醒摄像头，勿走完整 wakePeripherals（会踢 4G/重广播，弄断手机 BLE）
    if (camera.isSleeping() || !camera.isReady()) {
      (void)camera.wake();
    }
    setOv5640Flash(flashOn);
    gTorchOn = flashOn;
    char ack[72];
    snprintf(ack, sizeof(ack),
             "{\"type\":\"flash\",\"on\":%s,\"cam\":%s}",
             flashOn ? "true" : "false",
             camera.isReady() ? "true" : "false");
    ble_gatt::notifyEventJson(ack);
#else
    (void)flashOn;
#endif
  }
  if (appConsumeThumbRequest() && !gPipelineBusyFlag) {
    noteUiActivity();
#if USB_STREAM_ENABLE
    const bool resumeUsb = usbStream.isActive();
    usbStream.setActive(false);
    serviceDelay(30);
#endif
    // 取景只醒摄像头，避免 4G 自检卡住主循环
    if (camera.isSleeping() || !camera.isReady()) {
      if (!camera.wake()) {
        ble_gatt::notifyEventJson(
            "{\"type\":\"thumb\",\"ok\":false,\"reason\":\"wake_fail\"}");
#if USB_STREAM_ENABLE
        if (resumeUsb) {
          usbStream.setActive(true);
        }
#endif
        return;
      }
    }
#if !USE_MOCK_CAMERA
    camera.setStreamingPaused(true);
#endif
    CaptureResult thumb;
    if (camera.isReady()) {
      thumb = camera.captureThumbnail();
    } else {
      thumb.error = "camera not ready";
    }
#if !USE_MOCK_CAMERA
    camera.setStreamingPaused(false);
#endif
#if USB_STREAM_ENABLE
    if (resumeUsb) {
      usbStream.setActive(true);
    }
#endif
    if (thumb.ok) {
      ble_gatt::sendThumbJpeg(thumb.jpeg.data(), thumb.jpeg.size());
      ble_gatt::notifyEventJson("{\"type\":\"thumb\",\"ok\":true}");
    } else {
      // 固定 reason，避免错误串弄坏 JSON
      ble_gatt::notifyEventJson(
          "{\"type\":\"thumb\",\"ok\":false,\"reason\":\"capture\"}");
      Serial.printf("[APP] thumb fail: %s\n",
                    thumb.error ? thumb.error : "capture");
    }
  }

  if (state == AppState::ShowResult) {
    if (button.shortPressEdge() || button.longPressEdge() || button2.shortPressEdge() ||
        button2.longPressEdge()) {
      showIdle();
      setState(AppState::Idle);
    }
  } else if (state == AppState::Idle) {
    // KEY1/GPIO0：扫题；KEY2/GPIO42：唤醒 ↔ 休眠
    if (button2.shortPressEdge() || button2.longPressEdge()) {
      if (periphSleeping()) {
        Serial.println("[APP] KEY2 -> wake");
        if (!wakePeripherals("key2")) {
          showErrorHold("wake failed");
        } else {
          showIdle();
        }
      } else {
        Serial.println("[APP] KEY2 -> sleep");
        enterPeriphSleep();
        display.show(UiScreen::Idle, "已休眠 · KEY2唤醒");
      }
    } else if (button.shortPressEdge() || button.longPressEdge()) {
      Serial.println("[APP] KEY1 -> scan");
      triggerScanOrTest();
    } else if (appConsumeFixedAiTestRequest()) {
      runFixedImageSolvePipeline();
    } else if (appConsumeCaptureRequest()) {
      triggerScanOrTest();
    }
  }

  static String serialLine;
  while (Serial.available()) {
    const char c = static_cast<char>(Serial.read());
    if (c == '\r') {
      continue;
    }
    if (c == '\n') {
      serialLine.trim();
      if (serialLine.length() > 0) {
        if (serialLine.length() == 1) {
          const char ch = serialLine.charAt(0);
          if ((ch == 's' || ch == 'S') && state == AppState::Idle) {
            triggerScanOrTest();
          } else if ((ch == 't' || ch == 'T') && state == AppState::Idle) {
            runFixedImageSolvePipeline();
          } else if (ch == 'V') {
            noteUiActivity();
            usbStream.setActive(true);
          } else if (ch == 'v') {
            usbStream.setActive(false);
          } else if (ch == 'C') {
#if !USE_MOCK_CAMERA
            if (!appPipelineBusy()) {
              colorbarOn = !colorbarOn;
              camera.setColorbar(colorbarOn);
              if (!colorbarOn) {
                applyOv5640StreamTuning();
              }
            }
#endif
          } else {
            handleSerialLine(serialLine);
          }
        } else {
          handleSerialLine(serialLine);
        }
      }
      serialLine = "";
      continue;
    }
    // 仅无歧义单字符即时命令。勿把 s/t 放这里，否则 TTS/SAY= 会被吞掉
    if (serialLine.length() == 0 &&
        (c == 'V' || c == 'v' || c == '?')) {
      if (c == 'V') {
        noteUiActivity();
        usbStream.setActive(true);
      } else if (c == 'v') {
        usbStream.setActive(false);
      } else {
        String one;
        one += c;
        handleSerialLine(one);
      }
      continue;
    }
    if (serialLine.length() < 512) {
      serialLine += c;
    }
  }

  if (state == AppState::ShowResult && millis() >= result_until) {
    showIdle();
    setState(AppState::Idle);
  }

  // Error 屏停留后自动回 Idle 提示（此前状态已是 Idle，但 UI 卡在 OOPS）
  if (state == AppState::Idle && error_until != 0 && millis() >= error_until) {
    showIdle();
  }

  // 待机时电量/充电状态变化才整屏重绘；充电中只刷顶栏脉冲，避免闪屏
  static uint32_t lastBattUi = 0;
  static uint32_t lastChgAnim = 0;
  static int lastBattPct = -999;
  static bool lastCharging = false;
  if (state == AppState::Idle && error_until == 0) {
    if (millis() - lastBattUi > 2000) {
      lastBattUi = millis();
      refreshBattBadge();
      const int pct = battery::percent();
      const bool chg = battery::isCharging();
      if (pct != lastBattPct || chg != lastCharging) {
        lastBattPct = pct;
        lastCharging = chg;
        showIdle();
      }
    }
    if (battery::isCharging() && millis() - lastChgAnim > 400) {
      lastChgAnim = millis();
      refreshBattBadge();
      display.tickStatusBar();
      noteUiActivity();  // 充电时保持背光
    }
  }

  // 空闲：先关背光，再关摄像头/4G 射频；充电中/补光常亮/答案热点/USB 推流时不睡
  if (state == AppState::Idle && error_until == 0 && !battery::isCharging() &&
      !gTorchOn && !answer_ap::active()
#if USB_STREAM_ENABLE
      && !usbStream.isActive()
#endif
  ) {
    if (display.backlightOn() && IDLE_BACKLIGHT_MS > 0 &&
        (millis() - last_ui_activity) >= IDLE_BACKLIGHT_MS) {
      display.setBacklight(false);
    }
    if (IDLE_PERIPH_SLEEP_MS > 0 && !periphSleeping() &&
        (millis() - last_ui_activity) >= IDLE_PERIPH_SLEEP_MS) {
#if BLE_GATT_ENABLE
      // 手机连着时不睡摄像/4G，避免每次 App 扫题都先跑一整轮唤醒自检
      if (ble_gatt::isConnected()) {
        // 仅关背光省电；外设保持热待命
      } else
#endif
      {
        enterPeriphSleep();
      }
    }
  }

  delay(10);
}

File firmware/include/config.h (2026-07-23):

#pragma once

// 本地密钥与 WiFi（无 secrets.h 时用 example 占位）
#if __has_include("secrets.h")
#include "secrets.h"
#else
#include "secrets.example.h"
#endif

// ── 运行模式（默认全部真实硬件；仅开发板调试时用 mock 环境编译） ──
#ifndef USE_MOCK_DISPLAY
#define USE_MOCK_DISPLAY 0
#endif
#ifndef USE_MOCK_CAMERA
#define USE_MOCK_CAMERA 0
#endif
#ifndef USE_MOCK_MODEM
#define USE_MOCK_MODEM 0
#endif

#ifndef MODEM_PC_PASSTHROUGH
#define MODEM_PC_PASSTHROUGH 0
#endif

// FS-MCore-A7670G：PEN 使能 + PWK 拉低约 1.2s 开机（店家要求 PEN 常接 3.3V）
#ifndef MODEM_PULSE_PWRKEY
#define MODEM_PULSE_PWRKEY 1
#endif

#ifndef MODEM_BOOT_WAIT_MS
#define MODEM_BOOT_WAIT_MS 10000
#endif

#ifndef MODEM_FAST_PROBE
#define MODEM_FAST_PROBE 0
#endif

// ── AI 扫题解题（默认：智谱 GLM-V，OpenAI 兼容接口） ──
#ifndef USE_OPENAI_SOLVER
#define USE_OPENAI_SOLVER 1
#endif
#ifndef OPENAI_BASE_URL
#define OPENAI_BASE_URL \
  "https://open.bigmodel.cn/api/paas/v4/chat/completions"
#endif
// 首选视觉模型：付费最强 GLM-4.6V；用不了直接换 glm-4v-flash
#ifndef OPENAI_MODEL
#define OPENAI_MODEL "glm-4.6v"
#endif
#ifndef OPENAI_TIMEOUT_MS
#define OPENAI_TIMEOUT_MS 60000
#endif
// 单次扫题最多尝试几个视觉模型（遇额度耗尽/失败自动换）
#ifndef OPENAI_MODEL_MAX_TRIES
#define OPENAI_MODEL_MAX_TRIES 2
#endif

// 蜗牛移动：品牌≠制式。本机卡实测 IMSI 46001…/ICCID 898601… = 中国联通
// 固件会按 IMSI 自动选 APN；默认 wonet（联通），备用 cmiot/cmnet 等
// 电池电量：分压比 / 空满电压（磷酸铁锂请改阈值）
#ifndef BAT_DIVIDER_RATIO
#define BAT_DIVIDER_RATIO 2.0f  // Vbat = Vadc * ratio（100k+100k）
#endif
#ifndef BAT_V_EMPTY
#define BAT_V_EMPTY 3.30f
#endif
#ifndef BAT_V_FULL
#define BAT_V_FULL 4.20f
#endif
// 无独立 CHG 脚：进入「充电中」须看到充电/5V 轨；电压上升只用于维持状态。
// 勿用「满电电压≥4.15」或短暂回升单独进入充电——扫题后负载卸掉会误报。
#ifndef BAT_V_CHARGE_RISE
#define BAT_V_CHARGE_RISE 0.050f
#endif
#ifndef BAT_CHARGE_RISE_COUNT
#define BAT_CHARGE_RISE_COUNT 4
#endif
// 仅当分压还原电压明显高于锂电满电+噪声时才判充电轨。
// 7.0 太低：ADC 顶格≈3.3V×2=6.6～7.0 会误报；真接 5V 分压通常 ≥8V。
#ifndef BAT_RATIOED_CHARGE_RAIL
#define BAT_RATIOED_CHARGE_RAIL 8.0f
#endif

#ifndef CELL_APN
#define CELL_APN "wonet"
#endif
#ifndef CELL_APN_FALLBACKS
#define CELL_APN_FALLBACKS "cmiot", "cmmtm", "cmnet", "3gnet", "scuiot", "ctnet"
#endif

// 组网策略：默认只用 4G（不再连家用 WiFi / SoftAP）
#ifndef NET_CELL_ONLY
#define NET_CELL_ONLY 1
#endif
#ifndef NET_AUTO_SWITCH
#define NET_AUTO_SWITCH 0
#endif
#ifndef NET_PREFER_WIFI
#define NET_PREFER_WIFI 0
#endif
#ifndef WIFI_CONNECT_TIMEOUT_MS
#define WIFI_CONNECT_TIMEOUT_MS 15000
#endif
#if NET_CELL_ONLY
#undef USE_WIFI_FALLBACK
#define USE_WIFI_FALLBACK 0
#else
#ifndef USE_WIFI_FALLBACK
#define USE_WIFI_FALLBACK NET_AUTO_SWITCH
#endif
#endif

// WiFi 来自 secrets.h（CELL_ONLY 时忽略）
#ifndef WIFI_SSID
#define WIFI_SSID SECRETS_WIFI_SSID
#endif
#ifndef WIFI_PASS
#define WIFI_PASS SECRETS_WIFI_PASS
#endif

#define UPLOAD_HOST "httpbin.org"
#define UPLOAD_PATH "/post"

#define BUTTON_DEBOUNCE_MS 50
#define BUTTON_LONG_PRESS_MS 3000
#ifndef ERROR_HOLD_MS
#define ERROR_HOLD_MS 4000
#endif
#ifndef IDLE_BACKLIGHT_MS
#define IDLE_BACKLIGHT_MS 60000
#endif
// 空闲后关闭摄像头 + 4G 射频（AT+CFUN=0），按键/扫题时再唤醒
#ifndef IDLE_PERIPH_SLEEP_MS
#define IDLE_PERIPH_SLEEP_MS 90000
#endif
// 答案页停留（含 SoftAP 看全文）
#ifndef RESULT_HOLD_MS
#define RESULT_HOLD_MS 45000
#endif
// JPEG 质量：esp32-camera/jpge 数值越小画质越好（文件越大）
// 现走 ESP-TLS，可比较旧 HTTPDATA 路径放宽体积
#if NET_CELL_ONLY
#ifndef CAPTURE_JPEG_QUALITY
#define CAPTURE_JPEG_QUALITY 8
#endif
#else
#ifndef CAPTURE_JPEG_QUALITY
#define CAPTURE_JPEG_QUALITY 8
#endif
#endif
#define FRAME_WIDTH 640
#define FRAME_HEIGHT 480
// ESP-TLS 分片发送；放宽以便 cloud-safe 高质量软编码
#ifndef CELL_AI_MAX_JPEG
#define CELL_AI_MAX_JPEG 48000
#endif
// frame2jpg 质量 1–100，越高越清晰（与 OV5640 硬件 jpeg_quality 刻度相反）
#ifndef CLOUD_SAFE_JPG_QUALITY
#define CLOUD_SAFE_JPG_QUALITY 92
#endif
// 近黑/空图拒绝：体积小且熵低才丢；高熵小图（文字多、压得好）仍放行
#ifndef CLOUD_SAFE_MIN_JPEG
#define CLOUD_SAFE_MIN_JPEG 4000
#endif
#ifndef CLOUD_SAFE_MIN_DIVERSITY
#define CLOUD_SAFE_MIN_DIVERSITY 48
#endif
// 熵很高时允许略小体积（避免误拒清晰但压缩得好的帧）
#ifndef CLOUD_SAFE_RICH_DIVERSITY
#define CLOUD_SAFE_RICH_DIVERSITY 100
#endif
#ifndef CLOUD_SAFE_RICH_MIN_JPEG
#define CLOUD_SAFE_RICH_MIN_JPEG 3200
#endif

// 扫题捕获分辨率：1=优先 HVGA(480x320)，失败回退 QVGA（VGA 在本板易卡死）
// 智谱对 OV5640 硬件 JPEG 兼容性差 → cloud-safe 软编码；HVGA 提升字迹
#ifndef CAPTURE_USE_HVGA
#define CAPTURE_USE_HVGA 1
#endif
#ifndef CLOUD_SAFE_USE_HVGA
#define CLOUD_SAFE_USE_HVGA 1
#endif
// 装机朝向：镜头朝外壳正面外；微雪 C 型在 ESP32-S3 上常见需垂直翻转才「正前方朝上」
// 若画面仍反了，串口发 CAMFLIP / CAMMIRROR 切换，或改下面默认值重编
#ifndef CAM_VFLIP
#define CAM_VFLIP 1
#endif
#ifndef CAM_HMIRROR
#define CAM_HMIRROR 0
#endif

// 拍照前 OV5640 自动对焦（需模组 AF-VCC 接 3.3V，微雪 C 型通常已接）
#ifndef CAM_AUTO_FOCUS
#define CAM_AUTO_FOCUS 1
#endif

// 拍照自动补光（微雪 C 型镜头两侧灯，经 OV5640 STROBE）
#ifndef CAM_AUTO_FLASH
#define CAM_AUTO_FLASH 1
#endif
// 场景平均亮度 0x56A1 低于此值 → 开灯（AEC 未跟上的偏暗）
#ifndef CAM_FLASH_AVG_THRESHOLD
#define CAM_FLASH_AVG_THRESHOLD 40
#endif
// AGC 增益低字节 0x350B 高于此值 → 开灯（AEC 已拉满，环境仍偏暗）
#ifndef CAM_FLASH_GAIN_THRESHOLD
#define CAM_FLASH_GAIN_THRESHOLD 0x28
#endif
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

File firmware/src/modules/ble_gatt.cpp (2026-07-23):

#include "config.h"
#include "modules/ble_gatt.h"

#if !BLE_GATT_ENABLE

namespace ble_gatt {
bool begin() { return false; }
void loop() {}
bool isConnected() { return false; }
bool isReady() { return false; }
const char* advName() { return ""; }
bool selfCheck() { return false; }
void setPhase(const char*) {}
const char* phase() { return "idle"; }
void notifyAnswerChanged() {}
void notifyEventJson(const char*) {}
void sendThumbJpeg(const uint8_t*, size_t) {}
void restartAdvertising() {}
void disconnectAll() {}
}  // namespace ble_gatt

#else

#include "app_control.h"
#include "modules/ble_uuids.h"
#include "modules/solver.h"

#include <BLE2902.h>
#include <BLEAdvertising.h>
#include <BLEDevice.h>
#include <BLESecurity.h>
#include <BLEServer.h>
#include <BLEUtils.h>
#include <WiFi.h>
#include <esp_bt.h>
#include <esp_mac.h>

namespace {

BLEServer* gServer = nullptr;
BLECharacteristic* gStatus = nullptr;
BLECharacteristic* gCommand = nullptr;
BLECharacteristic* gAnswer = nullptr;
BLECharacteristic* gThumb = nullptr;
BLECharacteristic* gEvent = nullptr;

volatile bool gConnected = false;
volatile bool gNeedStatus = false;
volatile bool gNeedAnswer = false;
volatile bool gNeedAdvRestart = false;
bool gStarted = false;
char gAdvName[20] = "Saoti";
char gPhase[24] = "idle";
uint32_t gLastStatusMs = 0;
uint32_t gLastAdvKickMs = 0;
String gPendingEvent;

void notifyRaw(BLECharacteristic* ch, const uint8_t* data, size_t len) {
  if (!ch || !gConnected || !data || !len) {
    return;
  }
  const size_t chunk = 180;
  size_t off = 0;
  while (off < len) {
    const size_t n = (len - off) > chunk ? chunk : (len - off);
    ch->setValue(const_cast<uint8_t*>(data + off), n);
    ch->notify();
    off += n;
    delay(8);
  }
}

void notifyText(BLECharacteristic* ch, const String& s) {
  notifyRaw(ch, reinterpret_cast<const uint8_t*>(s.c_str()), s.length());
}

void pushStatus() {
  if (!gStatus || !gConnected) {
    return;
  }
  String j = appStatusJson();
  gStatus->setValue(j.c_str());
  gStatus->notify();
}

void pushAnswer() {
  if (!gAnswer || !gConnected) {
    return;
  }
  const String ans = solverLastAnswerText();
  if (ans.isEmpty()) {
    gAnswer->setValue("");
    gAnswer->notify();
    return;
  }
  char hdr[16];
  snprintf(hdr, sizeof(hdr), "LEN:%u\n", static_cast<unsigned>(ans.length()));
  String packet = String(hdr) + ans;
  notifyText(gAnswer, packet);
}

void startAdvInternal() {
  if (!gServer) {
    return;
  }
  BLEAdvertising* adv = BLEDevice::getAdvertising();
  // 已连接时 stop() 会弄断 iPhone/部分安卓链路 → App 点补光/取景「没反应」
  if (!gConnected) {
    adv->stop();
    delay(30);
  }

  // 31B 限制：ADV 只放 Flags+完整名，让安卓「设置→蓝牙」尽量能扫到名字；
  // Scan Response 放 Service UUID + 厂商魔数（App / iOS 主动扫描可读）。
  // 注意：iPhone「设置→蓝牙」永远不会列出自定义 GATT 设备，必须用 Companion App。
  BLEAdvertisementData advData;
  advData.setFlags(ESP_BLE_ADV_FLAG_GEN_DISC | ESP_BLE_ADV_FLAG_BREDR_NOT_SPT);
  advData.setName(gAdvName);
  adv->setAdvertisementData(advData);

  BLEAdvertisementData scanData;
  scanData.setCompleteServices(BLEUUID(SAOTI_BLE_SERVICE_UUID));
  {
    std::string mfg;
    mfg.push_back(static_cast<char>(0xFF));
    mfg.push_back(static_cast<char>(0xFF));
    mfg += "SAOT";
    scanData.setManufacturerData(mfg);
  }
  adv->setScanResponseData(scanData);

  adv->setScanResponse(true);
  adv->setAdvertisementType(ADV_TYPE_IND);
  // 单位 0.625ms：约 20–40ms，提高发现率
  adv->setMinInterval(0x20);
  adv->setMaxInterval(0x40);
  adv->setMinPreferred(0x06);
  adv->setMaxPreferred(0x12);
  // 三信道广播
  adv->setAdvertisementChannelMap(ADV_CHNL_ALL);
  BLEDevice::startAdvertising();
  Serial.printf("[BLE] advertising name=%s (use Companion App; iOS Settings will NOT list it)\n",
                gAdvName);
}

class ServerCallbacks : public BLEServerCallbacks {
  void onConnect(BLEServer* server) override {
    gConnected = true;
    gNeedStatus = true;
    Serial.println("[BLE] connected");
    // 勿在回调里 delay/重配广播（会弄断 iPhone）；交 loop 处理
    gNeedAdvRestart = true;
  }
  void onDisconnect(BLEServer*) override {
    gConnected = false;
    Serial.println("[BLE] disconnected — schedule advertising");
    gNeedAdvRestart = true;
  }
};

class CommandCallbacks : public BLECharacteristicCallbacks {
  void onWrite(BLECharacteristic* ch) override {
    std::string v = ch->getValue();
    if (v.empty()) {
      return;
    }
    String cmd;
    cmd.reserve(static_cast<unsigned>(v.size()));
    for (char c : v) {
      cmd += c;
    }
    cmd.trim();
    cmd.toLowerCase();
    Serial.printf("[BLE] cmd: %s\n", cmd.c_str());

    if (cmd == "ping") {
      gPendingEvent = "{\"type\":\"pong\",\"ok\":true}";
      return;
    }
    if (cmd == "scan" || cmd == "s") {
      appRequestCapture();
      gPendingEvent = "{\"type\":\"ack\",\"cmd\":\"scan\"}";
      return;
    }
    if (cmd == "wake") {
      appRequestWake();
      gPendingEvent = "{\"type\":\"ack\",\"cmd\":\"wake\"}";
      return;
    }
    if (cmd == "thumb" || cmd == "preview") {
      appRequestThumb();
      gPendingEvent = "{\"type\":\"ack\",\"cmd\":\"thumb\"}";
      return;
    }
    if (cmd == "flash=1" || cmd == "flashon") {
      appRequestFlash(true);
      gPendingEvent = "{\"type\":\"ack\",\"cmd\":\"flash\",\"on\":true}";
      return;
    }
    if (cmd == "flash=0" || cmd == "flashoff") {
      appRequestFlash(false);
      gPendingEvent = "{\"type\":\"ack\",\"cmd\":\"flash\",\"on\":false}";
      return;
    }
    if (cmd == "status") {
      gNeedStatus = true;
      return;
    }
    if (cmd == "answer") {
      gNeedAnswer = true;
      return;
    }
    if (cmd == "adv" || cmd == "advertise") {
      startAdvInternal();
      gPendingEvent = "{\"type\":\"ack\",\"cmd\":\"adv\"}";
      return;
    }
    gPendingEvent = "{\"type\":\"error\",\"reason\":\"unknown_cmd\"}";
  }
};

}  // namespace

namespace ble_gatt {
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

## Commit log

2026-07-09 Initial commit: 扫题挂件固件、macOS App 与硬件文档
    汇总 ESP32-S3 固件、SaotiCam 客户端与装配/3D 资料，便于开源与联调。
    [saoti_guajian_body.step, saoti_guajian_body.stl, saoti_guajian_lid.step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]
2026-07-17 更新固件与 v7.1 卡扣外壳，替换旧立方体 3D 模型
    同步工作区固件（屏/摄/4G/电源接线与模块），外壳改为按杜邦占位计算的 106×140×70 卡扣方案，并补充接线图与配件尺寸文档。
    [saoti_assembled_preview.stl, saoti_back.stl, saoti_front.stl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]
2026-07-19 整理完整工程并加入 BLE Companion App
    同步最新固件（BLE GATT、4G TLS 解题、电量），新增 iOS/Watch/Mac Companion，并更新接线文档与 README。
    [saoti_assembled_preview.stl, saoti_back.stl, saoti_front.stl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]
2026-07-19 修复 mock 环境下 USB 推流摄像头配置编译失败
    [camera.cpp]
2026-07-19 提升 AI 抓拍清晰度：HVGA 软编码、补光与近黑拒绝
    修复 cloud-safe JPEG 质量过低导致约 2KB 空图、模型认不出题的问题；测试模式在实拍不合格时回退内置测题图。
    [camera.cpp, config.h, main.cpp]
2026-07-19 外壳 v7.4：外接 6×6 键、后仓 70mm 净高与 20cm 线径审计
    补上 BOM 轻触开关的左壁 Ø12 孔与内凹座，加高后仓并收紧屏/摄线径，同步 STL/STEP 与打印说明。
    [saoti_assembled_preview.stl, saoti_back.stl, saoti_front.stl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]
2026-07-19 按 2 位独立按键模块改外壳 v7.5，并接 KEY2→GPIO42
    纠正原先按单颗 6×6 开孔；左壁改为双键窗+整板凹座，固件 KEY1 扫题 / KEY2 测 AI。
    [saoti_assembled_preview.stl, saoti_back.stl, saoti_packed_assembly.step]
2026-07-19 修复 iPhone 补光/取景断链，并改进取景清晰度与镜头朝向
    已连接时不再 stop 广播；取景/补光只轻量唤醒摄像头。BLE 预览升至 QVGA，默认 vflip，外壳镜头孔加大并略收偏心。
    [saoti_assembled_preview.stl, saoti_front.stl]
2026-07-19 为 Mac 端 SaotiCam / Companion 补上 AppIcon
    电脑端此前未配置资产目录；现加入 mac 图标集与 CFBundleIconName，并重新生成工程。
2026-07-23 整理仓库：去重外壳文件并上架外壳 v7.36
    删除 firmware/cad 与 case 根目录重复 STL、旧 zip、packed 中间件；外壳统一到 hardware/case；同步 TTS 与止口/壁厚修订。
    [saoti_assembled_preview.stl, saoti_back.stl, saoti_front.stl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]
2026-07-23 按体检清单完善稳定性：BLE 保活、接线文档与 App 端修复
    固件增加 serviceTick 在联网/解题等待中喂 BLE；取景失败早退并恢复 USB；停用 MODEM ALT 与 KEY2 冲突脚。Companion 修主动断开/LEN 收齐/Watch userInfo；SaotiCam 互斥串口与波特率提示；接线说明与 ASSEMBLY 对齐现行方案。
    [ble_gatt.cpp, main.cpp, modem.cpp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]
